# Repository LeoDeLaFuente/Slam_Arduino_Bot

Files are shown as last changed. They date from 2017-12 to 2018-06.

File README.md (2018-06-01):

Polytech

Ce projet est réalisé dans le cadre de la formation de prépa intégrée de Polytech'Nice Sophia
* * *
# Mapping with an Arduino Robot
&nbsp;&nbsp;&nbsp;&nbsp;&nbsp;&nbsp; Projet école de création d'un robot arduino permettant la cartographie d'une salle sans données GPS.

## Présentation

&nbsp;&nbsp;&nbsp;&nbsp;&nbsp;&nbsp;Slam Arduino Bot est un petit véhicule permettant de cartographier son environnement sans données GPS. 
Le robot est contrôlé par un utilisateur depuis un ordinateur. <br>

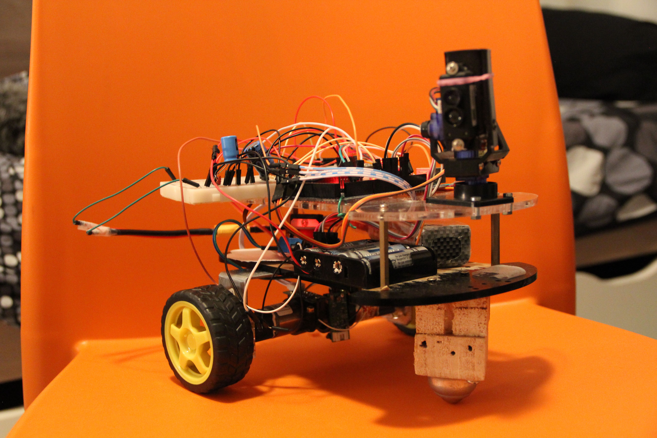
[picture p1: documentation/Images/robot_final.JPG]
Photo du robot


  &nbsp;&nbsp;&nbsp;&nbsp;&nbsp;&nbsp;Il se déplace, mesure des distances et transmet les données. Du côté de l’ordinateur, une application traite les données reçues, trace la carte 2D en fonction des données et envoie les ordres au robot.
Au début du fonctionnement, le robot s’initialise puis se connecte à l’application de l’utilisateur par wifi. Puis le robot commence à réaliser des mesures afin de scruter sont environnement. Il transmet les données à l’application qui les traites, et affiche la carte réalisée.  L’application attend les ordres de l’utilisateur concernant ses déplacements. Après avoir effectué les déplacements nécessaires, le robot va réaliser de nouvelles mesures et ainsi de suite.

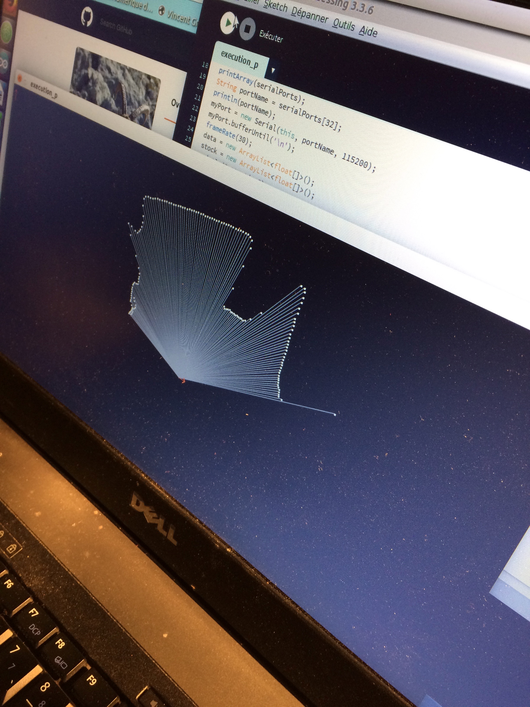
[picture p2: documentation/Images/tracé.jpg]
exemple de traitement de données


Ce projet est principalement réalisé avec une carte arduino Mega pour le robot et le logiciel processing pour l'application du coté ordinateur.

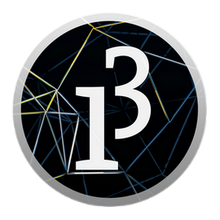
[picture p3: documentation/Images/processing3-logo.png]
Logo Processing


Après avoir travaillé à deux sur ce projet durant un semestre, nous avons finalement rendu ce <a href="/documentation/Slam Arduino Bot - compte rendu de projet.pdf">rapport</a> récapitulant notre travail.

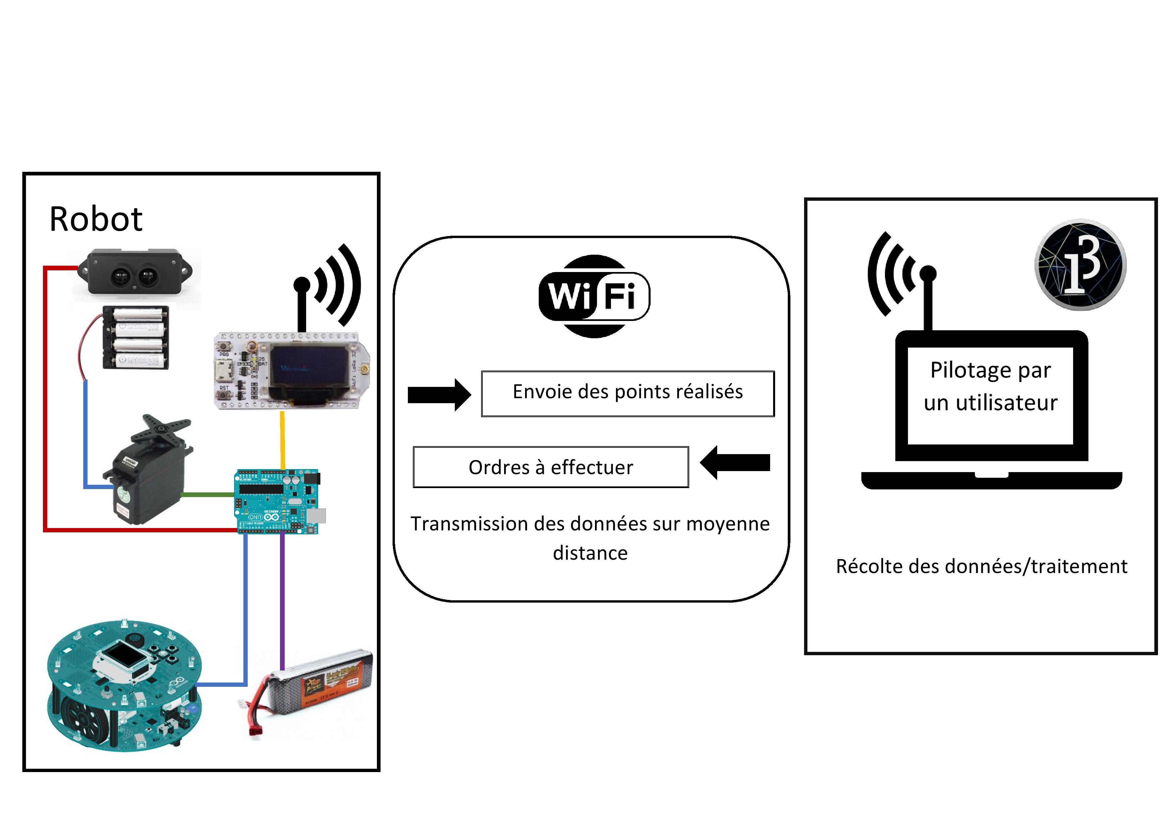
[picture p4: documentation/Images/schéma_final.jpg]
shéma projet


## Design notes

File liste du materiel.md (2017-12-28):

# Liste_du_matériel

Voici la liste du materiel que nous utilisons/utiliserons pour la réalisation de ce projet.

*****
#### ROBOT
- 2 arduinos  
  Nous utilisons 2 cartes ATMEL de type mini.
  Une carte sera embarquée sur le robot et permettra de commander les robot ainsi que de réaliser les mesures.
  Une seconde carte servira à réaliser une connexion radio fréquence avec le robot pour échanger les flux de données entre robot et ordinateur.

- carcasse  
  La carcasse du robot sera en deux etages, un premier étage où sera disposé les moteurs, la baterrie et la carte arduino. Et le second étage permetrera de fixer la tourelle de mesure.

- Antennes RF  
  Deux antennes radio fréquence permettant la communication entre les deux cartes arduinos. Antennes de type LORAM ?  

- Une batterie  
  Li

- tourelle :  
  + Un plateau pivotant  
  
  + servo moteur  
  de type ...   
  
  + laser de mesure de distance  
  de type ...  
   
  + compass ?   

- Déplacement:  
  + Deux roues codeuses  
  
  + Une roue folle

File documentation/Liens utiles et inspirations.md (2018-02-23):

# Voici une liste de tous les liens utiles

+ [transfers données arduino-ros](http://wiki.ros.org/rosserial_arduino/Tutorials/Arduino%20IDE%20Setup>)
  
+ [pdf](https://ocw.mit.edu/courses/aeronautics-and-astronautics/16-412j-cognitive-robotics-spring-2005/projects/1aslam_blas_repo.pdf)
 sur l'explication des techniques de S.L.A.M afin de traiter les données, d'en déduire son odométrie.
 
+ https://articulo.mercadolibre.com.ar/MLA-621770683-motorreductor-con-encoder-namiki-22cl-3501pg-_JM permet de savoir comment brancher nos roues codeuses
+ http://www.robot-maker.com/shop/blog/33_Asservir-moteurs-courant-continu-PID.html asservissement roue codeuse

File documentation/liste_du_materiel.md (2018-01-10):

# Liste du matériel

Voici la liste du materiel que nous utilisons/utiliserons pour la réalisation de ce projet.

*****

- 2 arduinos  
  Nous utilisons 2 cartes ATMEL de type mini.
  Une carte sera embarquée sur le robot et permettra de commander les robot ainsi que de réaliser les mesures.
  Une seconde carte servira à réaliser une connexion radio fréquence avec le robot pour échanger les flux de données entre robot et ordinateur.

- carcasse  
  La carcasse du robot sera composé de deux etages, un premier étage où sera disposé la baterrie et la carte arduino (ainsi que le systeme d'émission réception Lora) sur le dessus, et les moteurs sur le dessous. Et le second étage permetrera de fixer la tourelle de mesure.

- Antennes RF  
  Deux antennes radio fréquence permettant la communication entre les deux cartes arduinos. Ces antennes seront de type LORA permettant un échange de donné assez faible sur moyenne distance. 

- Une batterie  
  L'intensité demandé par les moteurs ne sera pas très élevé, mais nous utiliserons surement une batterie de type LiPoly que notre école à en stock, nous définirons la charge electrique et la tension nécessaire plus tard. 

- tourelle :  
  + Un plateau pivotant  
  
  + servo moteur  
  de type ...   
  
  + [laser de mesure de distance](/Construction_Projet/Laser.md)   
   
  + compas permettant une meilleure précision de rotation que les roues codeuses ???   

- Déplacement:  
  + Deux moteur/roues codeuses  
  
  + Une roue folle

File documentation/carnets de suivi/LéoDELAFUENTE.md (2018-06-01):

*******************
# Compte rendu 
*******************
## Présentation

Ce projet réalisé dans le cadre de notre cours d'arduino en PEIP2 de l'école Polytech Nice-Sophia (prépa intégré) consiste à conevoir un robot permettant de cartographier une salle. Nous allons pour cela utiliser une carte arduino.

## Seance du 21 Décembre
 - ##### Création du projet sous Github pour la remise des comptes rendus ainsi que le dépot de nos codes.
 - ##### Mise en place du projet
 - ##### Commencement de la mise en place de la liste du materiel
 - ##### Création du schéma du projet
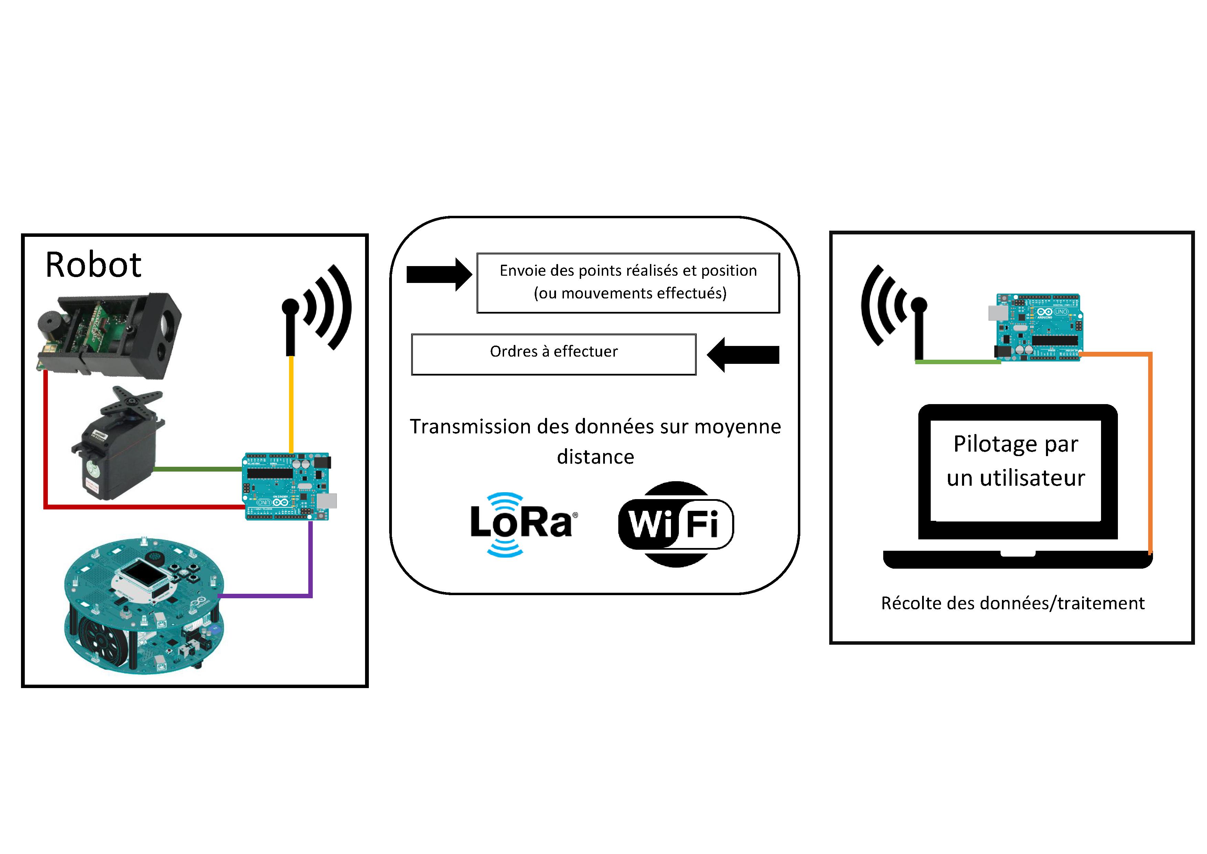
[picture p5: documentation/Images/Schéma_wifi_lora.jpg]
Schéma projet
 

 ## Travail personnel du 22 Décembre
 
  - ##### Commencement du [dessin 3d du robot](/robot) sous Autocad Inventor 
  La Base du robot sera constitué de deux planches en bois découpé à la découpe laser et reliés par quatre entretoises (en PVC ou métal). Un servomoteur sera placé sur la planche du dessus pour ensuite placer le télémetre laser dessus. Nous n'avons pas encore reçus les roues codeuses, et je n ai pas trouvé d'image 3D de celles-ci pour l'instant.
  
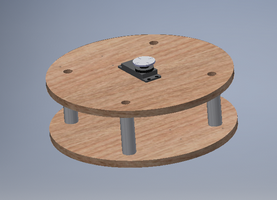
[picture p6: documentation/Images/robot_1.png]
Robot en 3D


## Seance du 10 Janvier 

 - ##### Reception du laser
 Notre professeur nous as soudé une alimentation permettant de faire fonctionné le Laser avec deux piles AA, ainsi ques les fils sur le pins Rx et Tx du laser. Félix à ainsi commencé a réaliser le code permettant de faire des mesures en boucle.
 
 - ##### Travail sur le servomoteur
  Le servomoteur que nous avons à disposition est un servomoteur étant sensé faire 180°.La rotation à 360° aurait été préférable, mais les servomteur pouvant réaliser des tours à 360° ne sont pas réellement des servomoteurs, ce sont des moteurs se comportant comme des moteurs à courant continues. Nous avons donc prévu d utiliser notre servomoteur de 180° et de demander à notre robot de faire un demi-tour sur lui meme si l 'on veux réaliser des points tout autour.  
Après avoir tester notre servomoteur 180°  nous avons constaté qu' il ne fait qu'environ 160° (amplitude exacte à définir.) Nous allons donc continuer avec celui-ci pour l instant, mais nous allons aussi surement voire pour commander un servomoteur effectuant 270° [comme celui-ci](https://fr.aliexpress.com/item/DOMAN-RC-DM-S0603D-40g-0-14s-5-5kg-cm-plastic-gear-300degree-robot-6kg-digital/32231859181.html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,searchweb201602_0_10152_10151_10613_10615_10614_10059_10314_10534_10084_100031_10083_10184_10305_10304_10307_10604_10306_10341_10065_10142_10340_10068_10343_10342_10103_10344_10302,searchweb201603_0,ppcSwitch_0&algo_pvid=1373983d-8d1d-41ea-bd80-e2dcfdbb8e0c&algo_expid=1373983d-8d1d-41ea-bd80-e2dcfdbb8e0c-20). 

## Séance du 19 Janvier

- ##### Reception des moteurs à roues codeuses
 Ayant reçu nos moteurs, je me suis penché sur leur fontionnement à l'aide d'un pont en H (L298N). Ce dernier permet de controler deux moteurs.  
 
 pont en h
 moteur à roues codeuses
  moteur à roues codeuses
 
 Nous appliquons une tension de 12V grâce à un générateur de tension pour nos tests. La mise en place du fonctionnement des moteurs à pris beaucoup de temps car j'avais utilisé un fil défaillant. Après avoir trouvé l'erreur, l'exécuion du programme permet defaire fonctionner les moteurs dans le sens voulu et de les arréter grâce aux touches du clavier. Nous avons récupéré le code présent sur [ce site](http://www.instructables.com/id/Arduino-Modules-L298N-Dual-H-Bridge-Motor-Controll/), ainsi que suivi les instructions. Ce programme m'as ainsi permit de comprendre comment fonctionne les moteurs pour pouvoir dévelloper le code qui va servir à diriger le robot.
 Il faut maintenant récupérer le signal des roues codeuses pour connaitre précisément la rotation des moteurs.  
 
 ## Séance du 22 Janvier
 
 - ##### Pésentation de notre projet devant nos deux professeur et notre classe.
 [La présentation est visible ici](https://github.com/LeoDeLaFuente/Slam_Arduino_Bot/blob/master/documentation/Slam_arduino_bot_presentation.pdf)
 
 - ##### Soudure des cables des roues codeuses.
 J ai effectué des soudure sur les fils des roues codeuse pour permettre le branchement sur notre plaque de test et relié ainsi le codage à l'arduino.
 
 ## Séance du 6 Fervier
 
 - #### Fonctionnement des roues codeuse.
  J ai fait plusieurs recherches pour trouver comment cabler la roue codeuse, et est trouvé un schéma qui n'était pas bon est qui a grillé les roues codeuse ( celle ci fontionne avec des leds, et je n'avait pas mis de résistances, sachant que le circuit de la roue codeuse n'en contient pas). J ai pu récupéré une roue codeuse avec un circuit de protection intégré qui fonctionne avec l'arduino. Il faut maintenant écrire le code permettant d'utiliser cette dernière, et acheter une seconde roue codeuse.
  
## Travail personnel du 9 Février

- #### Codage roue codeuse.
  J'ai réalisé un code ("moteur_execution") permettant defaire tourner une roue sur une longueur demandé en cm. Le programme prend donc une longueur l en cm, la convertit en "tour de roue", puis fais tourner la roue en comptant le nombre de tour graçeà la roue codeuse.

## Séance du 21 Février
- #### Fabrication du premier robot en carton.
 J'ai fabriqué le premier essai de robot en carton. Celui-ci va me permettre de faire premiers essai avec les roues codeuses et d'améliorer le fonctionnement de mon code.
 
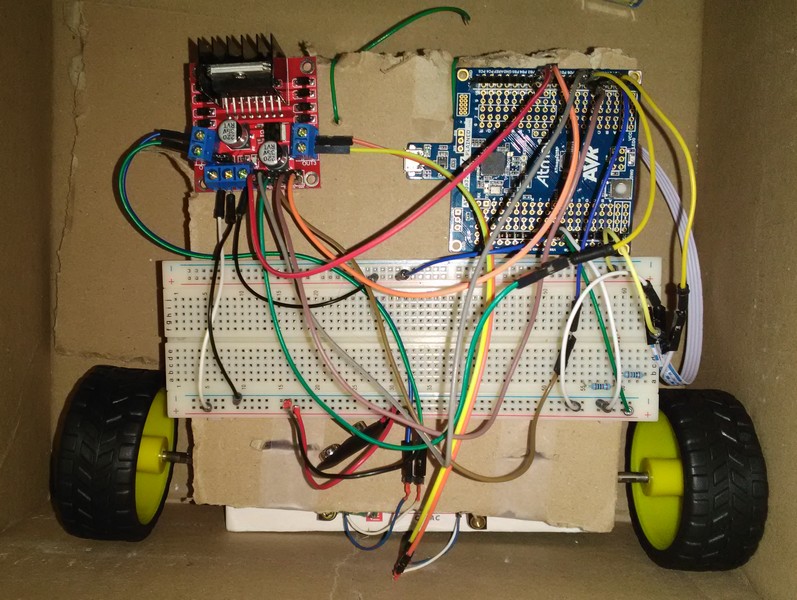
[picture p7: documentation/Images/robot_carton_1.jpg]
premier robot en carton


## Travail personnel du 22 Février
 - #### Mise en route du robot
    Après avoir récupéré une roue codeuse sur un robot d'un autre groupe qui ne s'en servait pas, j ai commencé à faire les essais pour faire tourner les roues du robot en même temps et commencer à programmer les mouvements élémentaires du robot. Je me suis aperçu que mes moteurs tournaient lentement, et pense que celà est dû au fait que j'alimente le pont en H et l'arduino avec la même pile de 9v qui n'est pas assez puissante.
    
## Séance du 12 Mars
 - #### Changement du support du robot
   J'ai récupéré un support différent permettant de faire de vrai test sur les déplacements du robot, mais il faut réadapter les moteurs pour qu'ils se fixent sur le support.
 
 ## fab lab le 20 Mars
 - #### Création d'une pièce d'adaptation
  J'ai réalisé à l'aide de la découpe laser une pièce permettant d'adaptater les moteurs à des equerres pour fixer le tout au support du robot. Il manque juste des rivets et la fixation sur le support.
  
 ## Séance du 28 Mars
 
 - #### Mouvements élémentaire
  J'ai réalisé une fonction permettant de faire avancer et reculer le robot, mais je n'ai pas pu le tester, car le robot n'est pas fini d'être monté. Je me suis par contre aperçu que les deux moteurs ne tournent pas à la même vitesse. Il va donc falloir réaliser un asservissement en vitesse sur les moteurs.
  
 ## fab lab le 3 Avril
 
 - #### Fixation des pièces avec rivets
 Après avoir acheté les rivets, je suis allé au fab lab pour fixer les moteurs aux equerres graçe aux pièces réalisé le 20 Mars. J ai aussi commencé à percer le support pour assembler les équerres au support.

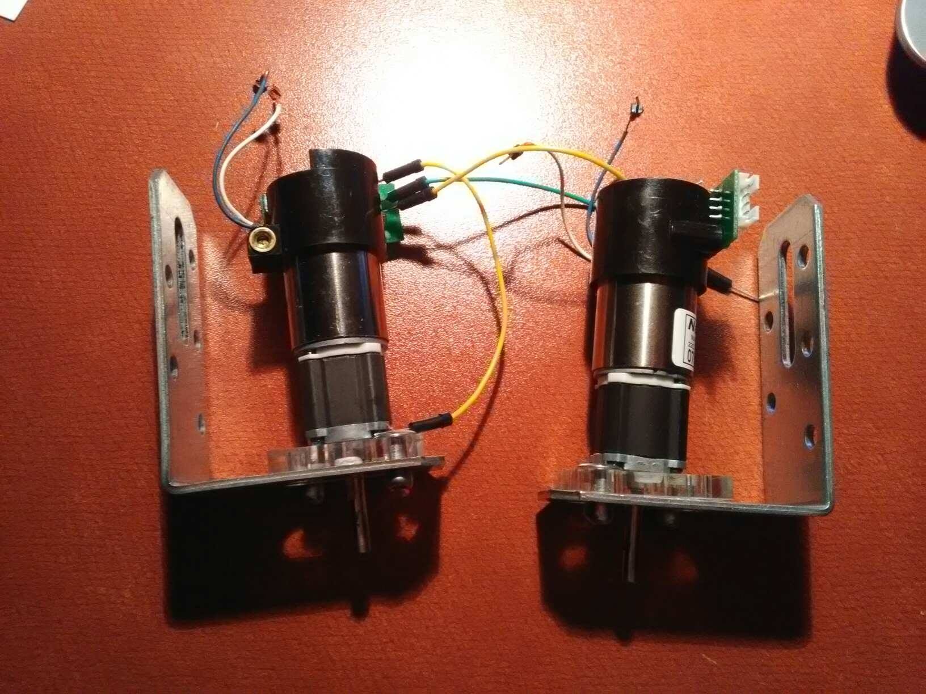
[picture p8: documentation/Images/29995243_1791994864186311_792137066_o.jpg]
assemblage equerre et moteur
  
 
 ## séance du 5 Avril
 
 - #### Présentation de mi-parcous auprès de nos professeur. 
 [Celle-ci est visible ici](https://github.com/LeoDeLaFuente/Slam_Arduino_Bot/blob/master/documentation/Slam_arduino_bot_mi-parcours.pdf). Elle nous a permit de rédéfinir notre planning et de faire le point sur notre projet.
 
 - #### Adaptations des roues.  
 Nous avons pu adapter les roues aux moteurs, nous n'avons donc finalement pas besoin d'en acheter de nouvelles.
 
 - #### Fixation des moteurs+équerres sur le support. 
 J ai rivetté les equerres sur le support, ce qui m'a permis de cabler l'ensemble moturs, pont en H, arduino et batterie sur le robot.
 <br>
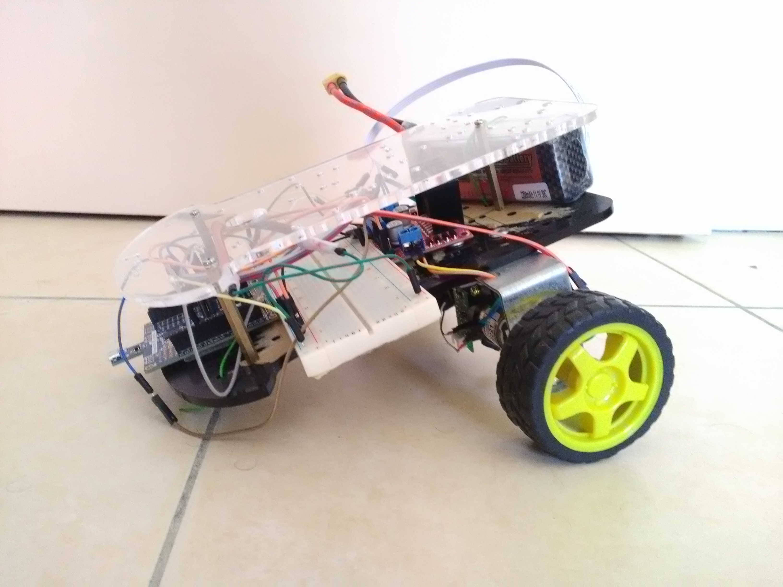
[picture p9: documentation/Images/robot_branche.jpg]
photo du robot
 
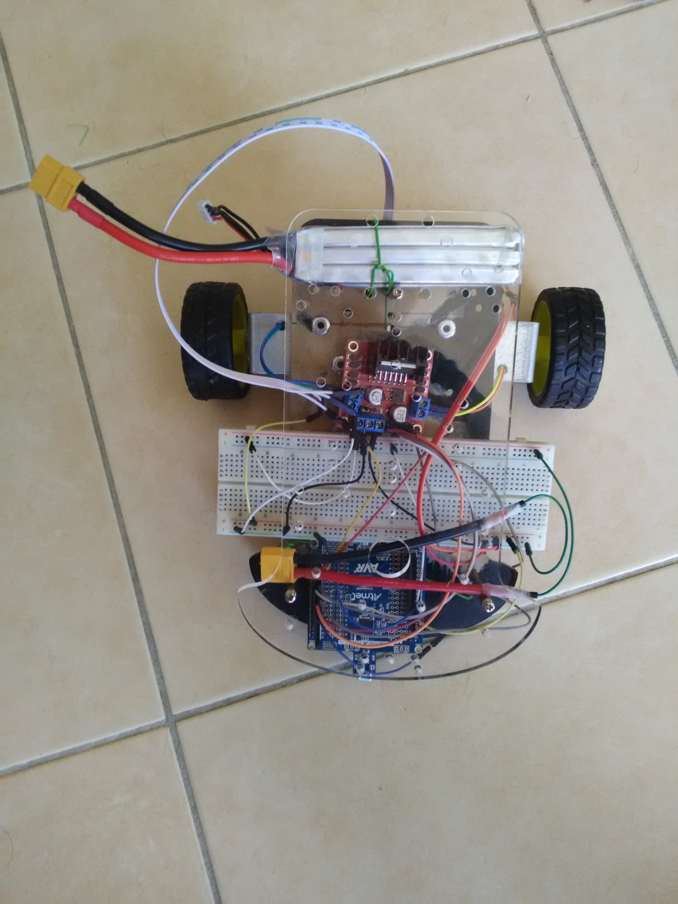
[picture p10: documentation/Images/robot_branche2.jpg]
photo du robot
 
 <br>
 [Voici la vidéo du premier branchement](https://youtu.be/iydBeL7KhAE).
 Il manque un pièce sur le devant pour surélever au dessus de la roue folle pour que le support reste bien plat, mais celui-ci n'est pas necessaire pour coder les déplacements du robot.

 ## fab lab et travail personnel du 6 Avril
 
 - #### Création de la dernière pièce manquante pour le robot
 Cette pièce en bois se situe entre le support et la roue folle pour que le dessus du robot soit de niveau.
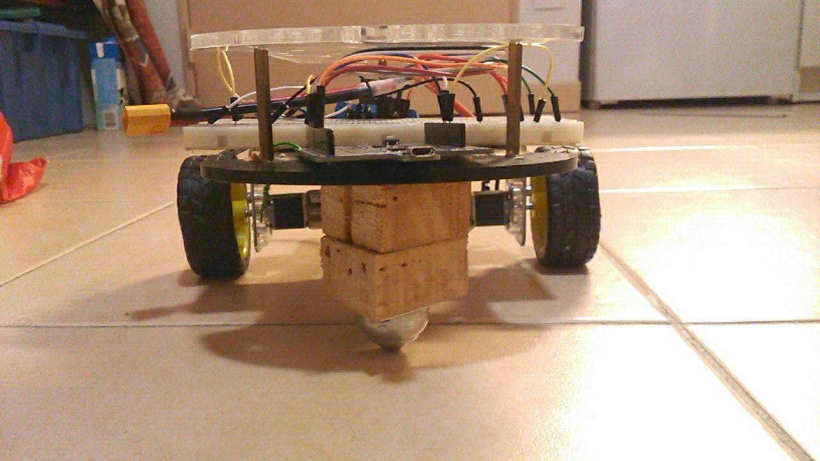
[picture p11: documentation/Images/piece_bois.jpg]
pièce en bois réalisé
 
 
 - #### Dévellopement du code sur le robot
 Le robot peut maintenant être commandé pour se déplacer en ligne droite sur une certaine distance, reculer, et tourner sur lui même dans les sens horaire et anti-horaire. [Cette vidéo montre les déplacements pouvants être effectués](https://youtu.be/h0HItliRpBA). On remarque que le robot ne se déplace pas en ligne bien droite, et que les rotations ne respectent pas bien les angles demandés (180 degrés puis 360 degrés). Cela est dû au fait que les moteurs ne tournent pas à la même vitesse. Il faut donc améliorer cela par un asservissement en vitesse des moteurs.
 
 - #### Recherche sur l'asservissement PID
  En effectuant des recherche sur l'asservissement des moteurs, j ai trouvé un code permettant de réaliser un asserviement PID, mais je n'arrive pas à adapter les constantes de proportionalité, de dérivation et d'intégration à nos moteurs.
 
 ## Travail personnel du 8 Avril 
 - #### expérimentation frottements
 Pour essayer "d'échapper" à l'asservissement en vitesse necessaire pour que les deux moteurs tournent à la même vitesse, j ai essayé de voire si le frottement des les moteurs suivait une loi linéaire, et si un coefficient e proportionnalité pouvait être trouvé entre les deux moteurs.
 Malheureusement ce paramètre ne semble pas linéaire, et je n'ai pas trouvé de coefficient de proportionnalité entre les vitesse de mes deux moteurs.
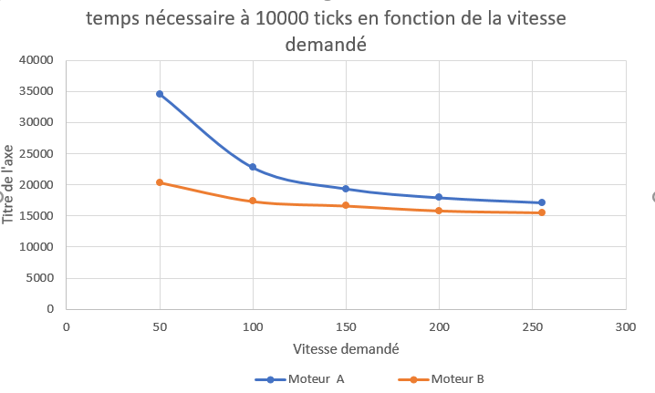
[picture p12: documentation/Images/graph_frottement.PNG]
graph du temps pour réalisé 1000ticks en fonction de la vitesse demandé des deux moteurs
   
 [Voici la feuille excel qui a produit le graph](/documentation/tableur_frottements.xlsx)  
 Le code ayant permit de faire ces calcul est un code modifié du code "robot réel" et nommé "calcul_frottements_moteurs [situé  ici](/code/autres_codes_arduino). Les mesures ont été doublé pour chaque valeur de vitesse et moteur pour avoir un résultat plus précis.

## Travail personnel du
- #### travail sur l'asservssement
## Travail personel du 27 Avril

- #### Compilation des codes asservisseent et robot_reel. Le robot ne reste stoujours pas prècis a cause du fait que le support du robot est légèrement décalé, et que les roues ne sont pas bien rondes.
Un bug est apparu sur la carte arduino : avrdude: stk500_recv(): programmer is not responding, que je ne suis pas arrive, même en réinstallant l'ide arduino. Jai donc continué à travailler avec la carte de Félix, mais après une quinzaine de téléversement, cette seconde carte à rencontré le même problème.

## Séance du 2 Avril 

- #### Résolution de l'erreur lors du téléversement.
Nous avons réinitialiser la carte, et le téléversement refonctionne (jusqu'à quand ? ). 

- #### Essai du code et amélioration des valeurs.
Les roues n'étant pas exactement parrallèles entre elles, le valeur de l'entraxe des roues tait difficilement mesurable. J ai donc procédé par tatonnement pour trouver la meilleur valeur. Le robot ne semble pas avoir d'erreur après 6 tour sur lui même dans le sens anti horaire. J ai désctivé la fonction permettant de faire des tours dans le sens horaire car celle-ci necessiterai une valeur d'entraxe un peu différente ( en exécutant 6 tour, le robot cumul une valeur d'environ 10 degrés.

## Travail personnel du 3 Avril

- #### Combinaison du lidar et du robot.
J ai regroupé les cablages du robot et du lidar sur l'arduino mega ainsi que créé un code qui est la combinaison des deux. Ainsi le robot peux maintenant se déplacer par exemple de 35 cm , faire des mesures avec le lidar, exécuter un demi-tour, puis refaire une mesure, et continuer ainsi. Il faut donc maintenant gérer les différents évènements qui vont arriver par la connexion wi-fi, pour les faire exécuter par le robot, et renvoyer les valeurs mesurées à l'ordinateur.  

[Cette vidéo montre un test du nouveau code (assemblage_1)](https://youtu.be/nSwKWuOiDY0)

## Séance du 9 Avril

- #### Travail sur les commandes du robot
J ai changé le code pour pouvoir permettre des actions simple sur le robot tout en effectuant nos mesures

## Séance du 2 Mai

- ####  Réorganisation
Pour pouvoir mieux travailler sur le projet, j ai changé les emplacements des modules : les alimentations en dans l'étage inferieur du robot, et les cablages sur le dessus. J'ai eu beaucoup d'erreurs qui se sont ajouté au robot suite à cette réorganisation. 

## Séance du 7 Mai

- #### Débogage des erreurs lié à la réorganisation
J ai du consacré une séance entière pour pouvoir comprendre d'où venaient les erreurs. 
- #### Réparation du module lidar
Notre module Lidar peut parfois commencer à bugger en renvoyant que des valeurs de distance constantes. Ces données sont donc inutilisable. J ai donc tenté de réparer  cela en ajoutant une capacité plus conséquentes entre l'alimentation et le lidar. En efet nous pensions que des appels de courants trop fort du lidar faisant que le courant de venaittrop faible pour l'alimenter. 
Cette capacité n'a pas sembler améliorer le lidar.

## Travail personnel du 25 Mai
- #### Assemblage
Nous avons travaillé ensemble avec félix pour pouvoir assembler tout le projet e final.  Nous avons un bug entre la liaison série de lrduino et l esp que nous ne comprenons pas.
- #### Rédaction
Nous avons profiter de cette séance pour commencer à rédiger le rapport

## Travail personnel du  31 Mai
- #### réorganisation, préparation de la présentation
Nous avons tenté de résoudre les bugs autour de la connexion, mais ceux-ci nous sont incompréhensible. Nous avons donc préparer notre présentation et préparer les codes pour les différentes fonctionnalités des modules.

## Séance du 1 Juin
- #### Présentation de notre projet devant la classe et nos professeurs.

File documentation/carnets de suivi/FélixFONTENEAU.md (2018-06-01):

# Cahier de suivi du projet de Félix Fonteneau

## Séance du 20 Décembre 2017

Tâches effectuées :

  + Recherches bibliographique des différentes options permettant d'aboutir à réaliser le traitement de données sur l'ordinateur (processing/ROS).

  + Décomposition des différents besoins matériels et informatiques nécessaires au projet. Schématisation de l'ensemble des modules et de leur utilités au brouillon : 
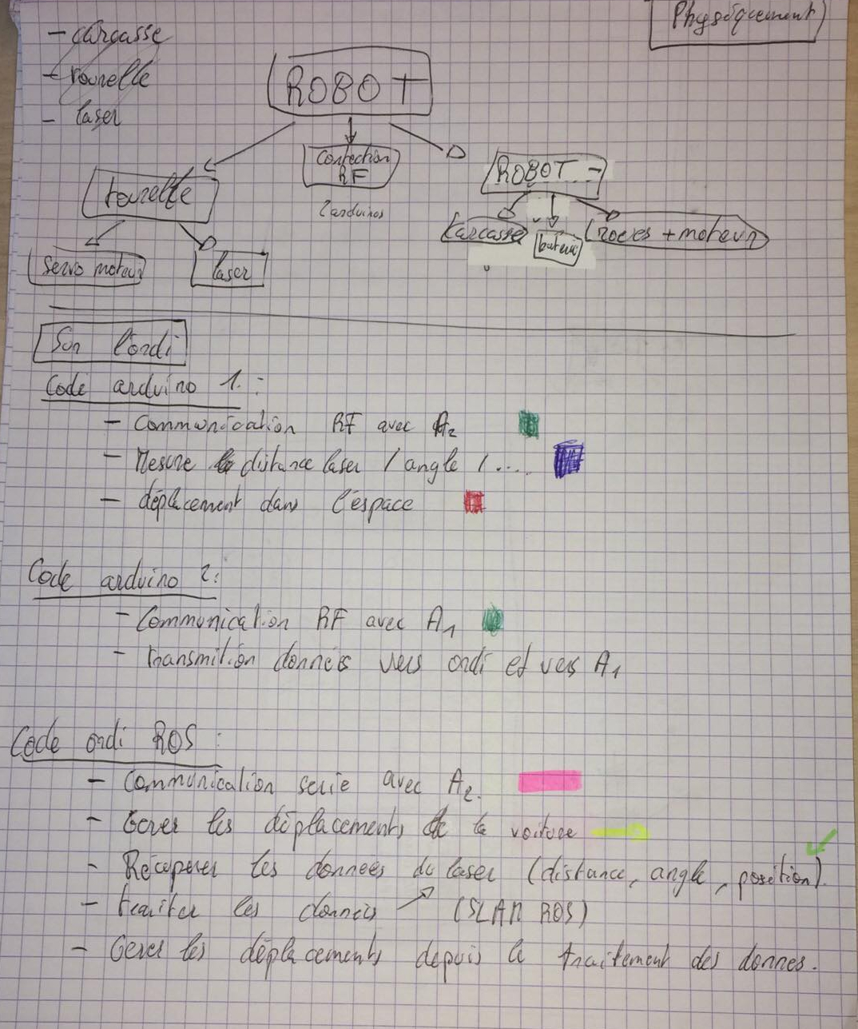
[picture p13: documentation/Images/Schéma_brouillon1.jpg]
brouillon
    
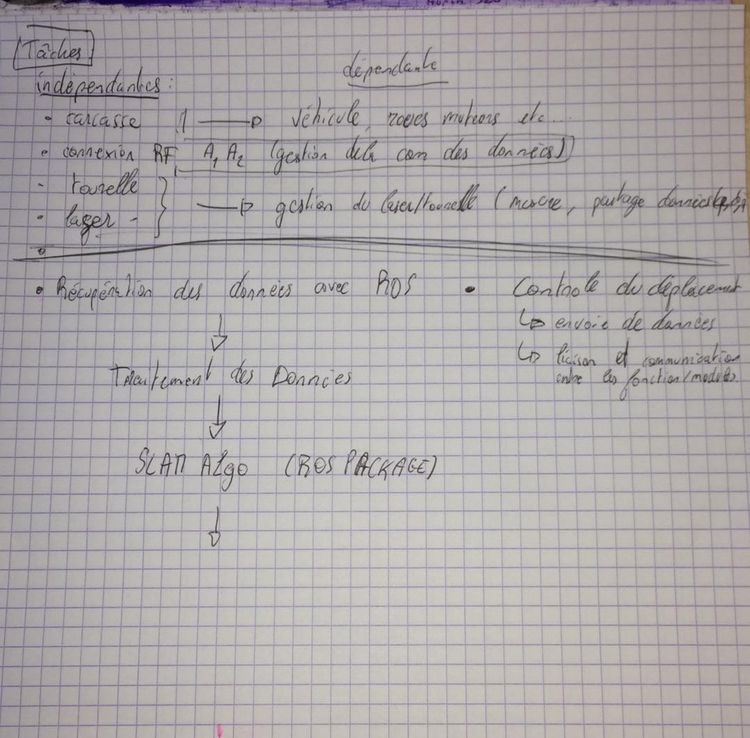
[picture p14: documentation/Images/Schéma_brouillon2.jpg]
brouillon2
  
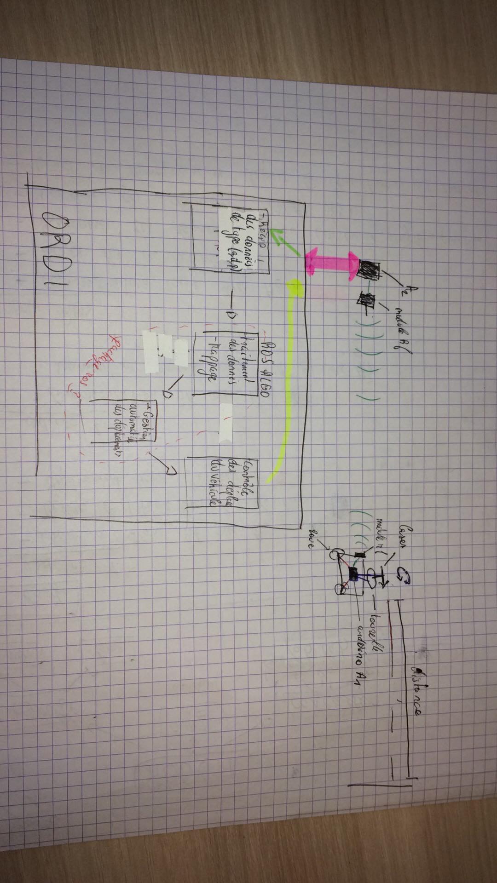
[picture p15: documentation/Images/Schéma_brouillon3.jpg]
brouillon3
  
  
  + Mise en place et déveleppement du GitHub.  
  
***  

## Travail personnel entre les séances 

Tâches effectuées :
  + Recherches et dévellopements des idées à la réalisation.  
  
  + Liste du matériel : [liste](/documentation/liste_du_materiel.md)
 
 ***  

## Séance du 8 Janvier 2018

Tâches effectuées :
  + Réception et début d'utilisation du module laser. Débuts concluants pour les premiers tests avec le laser. En effet il marche parfaitement dans les conditions dont le souhaitons. Voir : [code basique laser automatique]( /code/arduino files/test_laser_san_delay/test_laser_san_delay.ino)
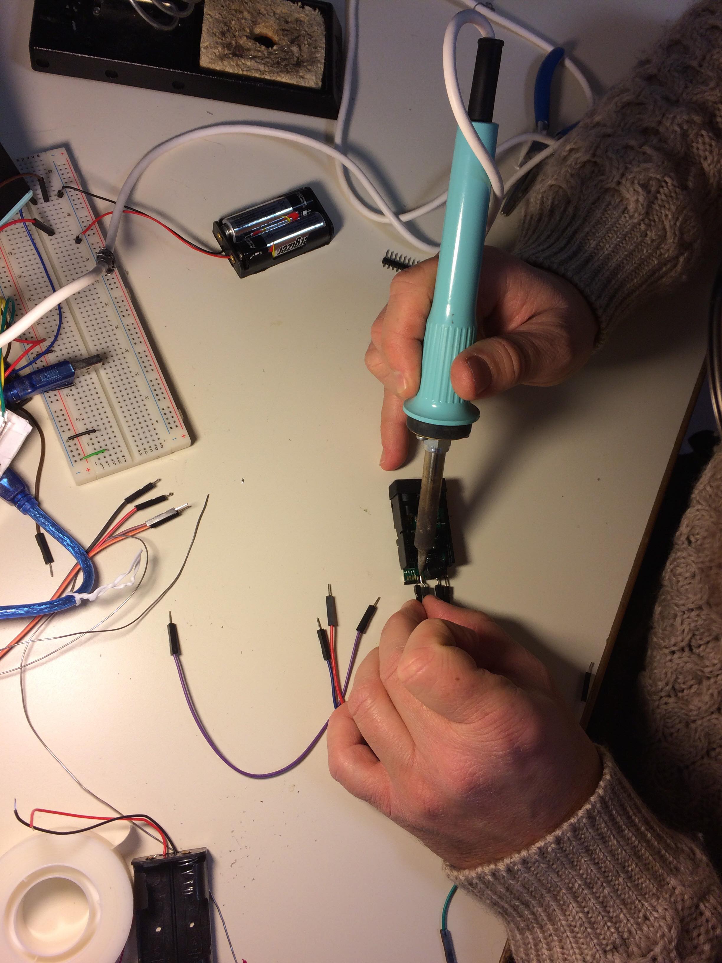
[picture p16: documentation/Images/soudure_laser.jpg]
photo soudure
  
  
  + Création de la présentation du module laser : [ici](/Construction_Projet/Laser.md)
  
  ***  
## Travail personnel entre les séances

Tâches effectuées :
  + Optimisation du code du laser
  
  + Amélioration de la vitesse des mesures
  
  ***  

## Séance du 19 Janvier 2018  

Tâches effectuées :
  + Réception des moteurs à roues codeuses (voir le carnet de léo)
  
  + Création de la première tourelle temporaire avec fil et scotch. La premiere tourelle est peu précise mais donne deja une premiere vision de la gestion des données et de comment ameliorer sa précision.
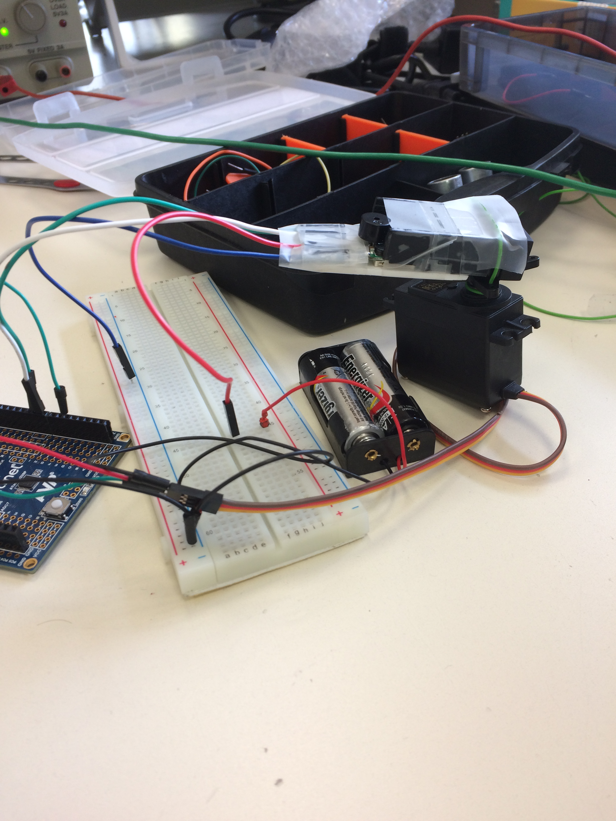
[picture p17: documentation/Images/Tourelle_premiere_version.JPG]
image tourelle
  
  
  + Harmonisation du code entre servo moteur et laser [code laser](/code/arduino_files/Tourelle/Tourelle.ino )
  
    ***  

## Séance du 22 Janvier
 
 - ##### Pésentation de notre projet devant nos deux professeur et notre classe.
 [La présentation est visible ici](https://github.com/LeoDeLaFuente/Slam_Arduino_Bot/blob/master/documentation/Slam_arduino_bot_presentation.pdf)
 
   ***  

## Travail personel durant la semaine de ski

Tâches effectuées : 
  + Création d'une simulation du laser pour débuter la programation, <a href="code/computer files/processing/execution_p/execution_p.pde"> code processing </a>
  
  + Début du traitement des données sur processing. 
  
  + Création de l'interface et de l'affichage de la carte en fonction des données reçues  
  <a href="code/computer files/processing/execution_p/execution_p.pde"> code </a>
  Cela permet de nous donner une base afin de pouvoir commencer la partie programmation en parallèle de la partie électronique.  
  
  + Le code  et l'interface sont plutôt ajustable pour convenir a des quelconques changements de projet.
  
    ***  

## Séance du 07 Février
 
 - PROBLEME   Face au trajet durant la semaine de ski, le laser a du faire un faux contact avec les piles probablement.
 
 - Tentative de ressoudage des soudures en vain.
 
 - Comparaison de l'impédance totale du laser avec l'impédence d'un laser fonctionel de même marque.  
 On remarque que les impédences sont totalement différentes (laser test de l'ordre de la dizaine d'Ohms, laser fonctionel de l'ordre du méga Ohms)
 
 - Solution : pret d'un nouveau laser pour continuer le projet.
 
   ***  

 ## Travail personel entre les séances  
 
  - Remise en état de la tourelle, mais problèmes de précision ainsi que de montage concernant cette dernière. En effet fixer stablement et précisement le laser sur la tourelle est délicat. Les cables reliant le laser au module arduino sont peu souples et tirent lors des changement d'orientation pouvant potentiellement troubler les mesures.
 
   ***  

## Séance du 21 Février

  - Changement de voie pour les mesures télémétriques du robot. 
  
  - En effet la tourelle munie d'un servo moteur permet d'effectuer environs 3 mesures par secondes avec une précision à revoir (stabilité sur la tourelle).
  
  - Mr P. Masson a commandé un Lidar pour tester cette posibilité.  
  Le lidar permetrai des mesures en "continu" et sur un axe en rotation continu. Cela augmenterai la rapidité de cartographie de notre systeme.
  
  - Les avantages :
    + Beaucoup plus de mesures effectuées.
    + Une meilleure précision grace à un nombre plus conséquent de mesures.
    + Lidar en rotation sur un axe. Cette rotation s'effectuera avec un moteur à rotation continu et une roue codeuse (pour savoir la vitesse angulaire du Lidar).
  
  - Les désavantages sont :
    + Une moins bonne précision et capacité de mesure des distances (12 m pour le Lidar, 40m pour le laser actuel). 
    + Mise en place d'une tourelle à rotation.
    + Transfert difficile pour les câbles (gestion de l'entortillement des câbles du lidar sur la tourelle).
  
  - La solution pour cette dernière difficultée est de peut être d'utiliser un slip-ring pour faire passer les cables.
  
  ***
  
## Travail personel entre les séances  
 
  - Peu de travail fut fourni sur la tourelle entre ces deux séance, j'étais en attente des pieces. Donc j'ai profité pour améliorer le code Processing. 
  
  - Arrivé du lidar peu de temps avant la scéance du 28 Mars.
  
  ***
  
## Séance du 28 Mars
  
  - Récupération d'un lidar monté sur deux servo moteur. 
  
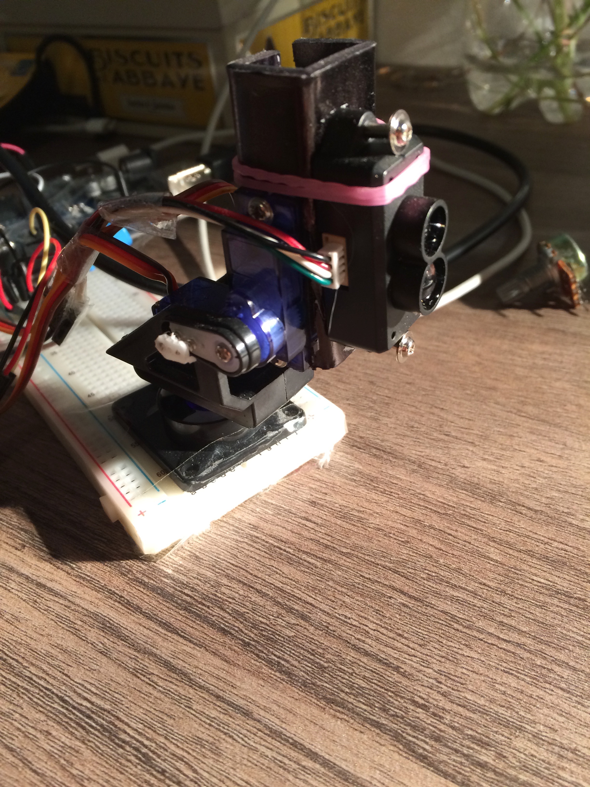
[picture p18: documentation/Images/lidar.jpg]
   
  
  - Ce Lidar n'est pas monté sur un moteur à rotation continue, il n'a donc pas besoin de slip ring pour faire passer les câbles. 
  
  - Lidar rapide (100Hz) mais la vitesse d'execution stable est plus lente environ 60Hz. 
  
  - Le lidar beug parfois et affiche une valeur en boucle pendant une centaine de mesures, problème à corriger par la suite.
  
  - Mais avant tout ce Lidar est bien mieux adapté à notre projet.
  
  - Il reste maintenant à bien adapter le fonctionnement de ce lidar au code déjà existant. Puis il faut que j'attaque les communications RF.

   ***
  
## Séance du 05 Avril 

  - Présentation de l'avancement de notre projet au reste du groupe. La voici : <a href="documentation/Slam_arduino_bot_mi-parcours.pdf" > ici </a>.
  
  - Problèmes de mesure avec le lidar. Il y a des sursaut avec le lidar de plus l'arduino mega a parfois du mal à gérer le servos moteurs aisi que les mesures.
  
 ***
  
## Travail personel entre les séances 

  - Début de construction du module RF reliant le robot à l'ordinateur. Pour cela nous allons changer un peu le le schéma de notre projet. En effet, vu le débit d'informations possibles à passer, nous allons utiliser la carte ESP 32 avec son port wifi. Le robot pourra donc immédiatement communiquer avec l'ordinateur avec une communication wifi. Le robot et l'ordinateur seront dans un premier temps connecté à un réseau commun.

  ***
  
## Séance du 10 Avril 

  - Continuité de la télécomunication wifi avec la carte esp32. 
   - Fin du module laser ! Le lidar marche enfin (presque à la perfection) et le code d'affichage est opérationnel. 
   

***
  
## Travail personel entre les séances 

  - Travail long et fastidieux sur la carte esp32.

  - L'utilisation de la carte esp 32 est difficile au début. En effet elle demande pas mal de documentation sur son paramétrage avec l'IDE arduino. De plus la connexion Wifi n'est pas très facile à gérer et demande beaucoup de temps.
  
  - Fin de la communication Wifi entre la carte esp 32 et processing. Pour cela, la carte esp 32 va se connecter à l'ip de l'ordinateur et arriver sur le server processing. Le code sur processing est très similaire à n'importe quel serveur java. Pour optimisation, on va d'abord connecter les deux éléments ensemble avec un mot de passe etc. Puis par soucis d'éfficacité, n'envoyer que les informations nécessaires par wifi.
  Cette partie m'a pris beaucoup de temps et d'investissement car elle a été difficile à cerner, puis à réaliser avec de nombreux diffonctionnements entre les connexions avec un hotspot wifi. 
  
    ***
  
## Séance du 04 Mai

  - Harmonisation du code du serveur processing, et du code de traçage de la carte en 2d.
  - Optimisation de l'application.
  
  ***
  
## Travail personel entre les séances 

  - Améliorations des échanges entre l'esp32 et l'application processing.
  
  - Création d'une simulation de nuage de points avec l'esp32 à distance.
  
   ***
  
## Séance du 14 Mai
  
  - Soudure des pins de l'esp32.
  
  ***
## Travail personel final 

  - Harmonisation finale des deux cartes (méga et esp32). Cette tâche fut de loin la plus dure et la plus compliquée. Elle fait intervenir plusieurs éléments avec beaucoup de lignes de code. Une capacité d'abstraction et de prise de recule fut nécessaire pour faire face aux problèmes rencontré. 
  
  - Au final, la connexion série entre l'esp32 et la Méga pose beaucoup de problèmes. Après de nombreusess heures à être passé à essayer de recabler ou de filtrer les données transmises. Nous n'avons pas reussi à gerer cette petite liaison qui aura causé la chute de notre projet. 


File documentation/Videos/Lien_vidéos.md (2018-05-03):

 ## Voici les liens des vidéos prises durant la réalisation du projet
 
 <hr>
 
 - #### [Premier banchement](https://youtu.be/iydBeL7KhAE)
 
 - #### [premiers déplacements élémentaires](https://youtu.be/h0HItliRpBA)
 
 - #### [Test robot + lidar](https://youtu.be/nSwKWuOiDY0)

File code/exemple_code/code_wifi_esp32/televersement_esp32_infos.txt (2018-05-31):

Afin de pouvoir televerser du code sur la carte esp32 de Heltec,
je vous redirige vers le github du constructeur expliquant tout en détail.

https://github.com/espressif/arduino-esp32

Puis regardez sur le read_me installation instructions.

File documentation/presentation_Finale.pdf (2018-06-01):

## SLAM ARDUINO BOT

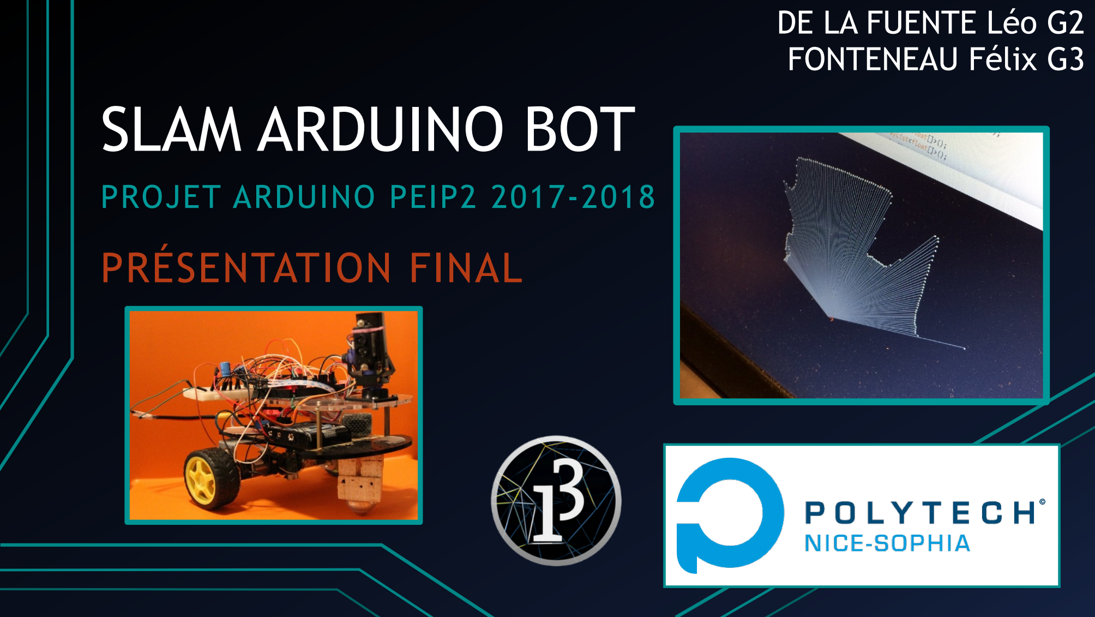
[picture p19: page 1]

PROJET ARDUINO PEIP2 2017-2018
PRÉSENTATION FINAL

DE LA FUENTE Léo G2
FONTENEAU Félix G3

## Sommaire

- Rappel du projet/changements
- Lidar
- Robot
- Connexion wifi
- Problèmes /Ce qu’il manque
- Planning et respect des tâches
- Conclusion

## Rappel du projet

Cartographie par robot en intérieur (sans données gps) avec un utilisateur dirigeant la robot à distance

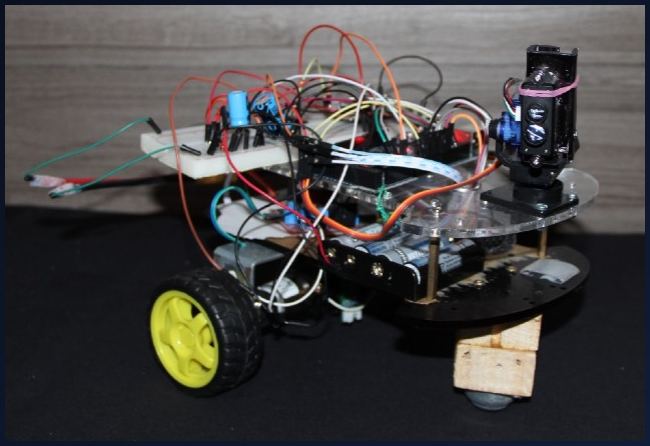
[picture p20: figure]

## Rappel du projet

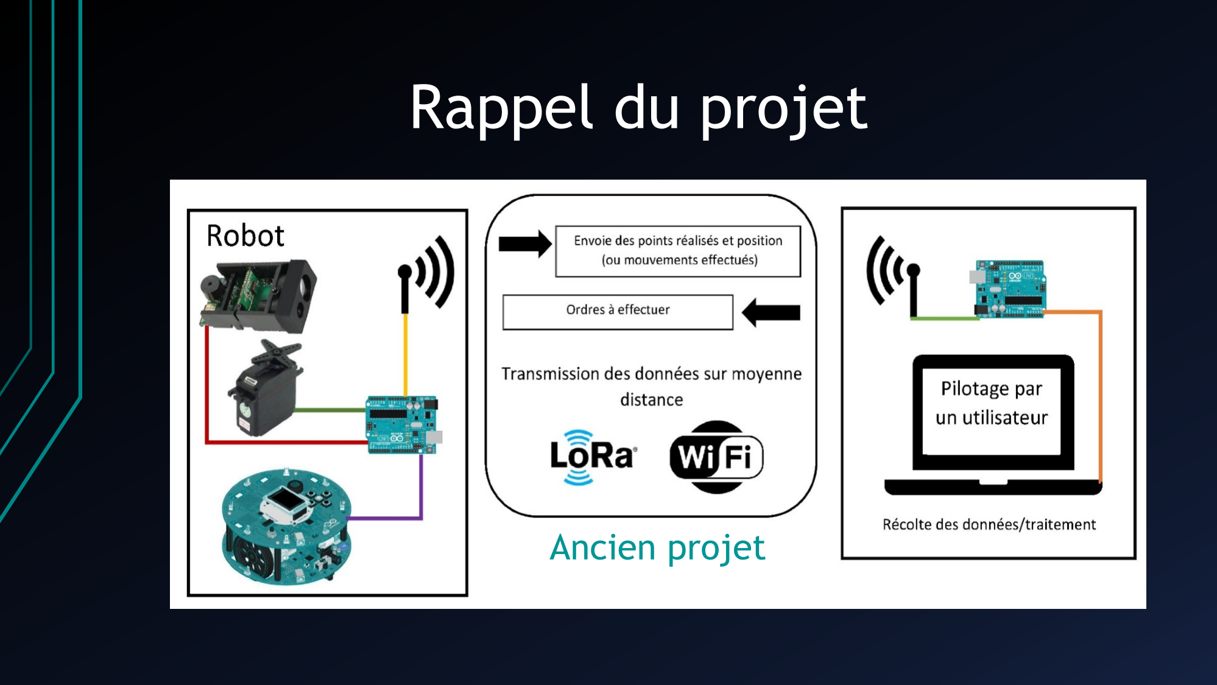
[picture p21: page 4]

Ancien projet

## Rappel du projet

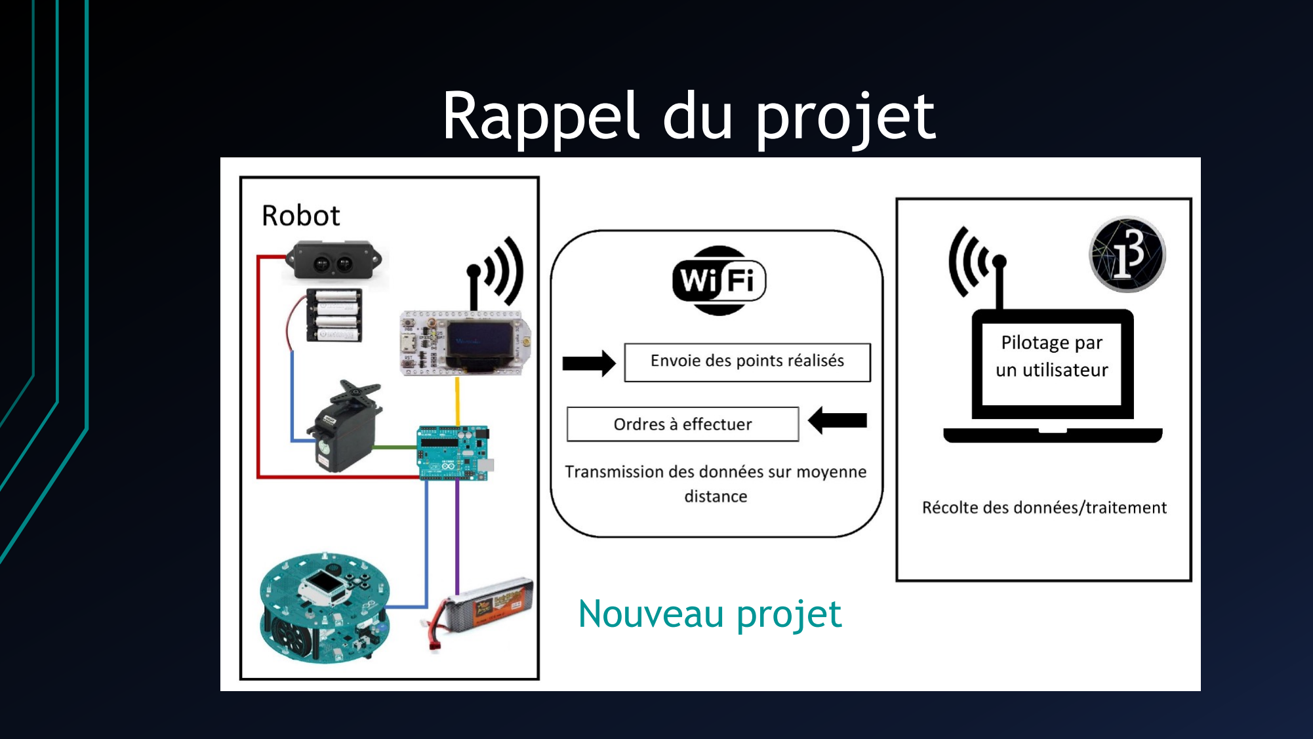
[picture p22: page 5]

Nouveau projet

### Lidar

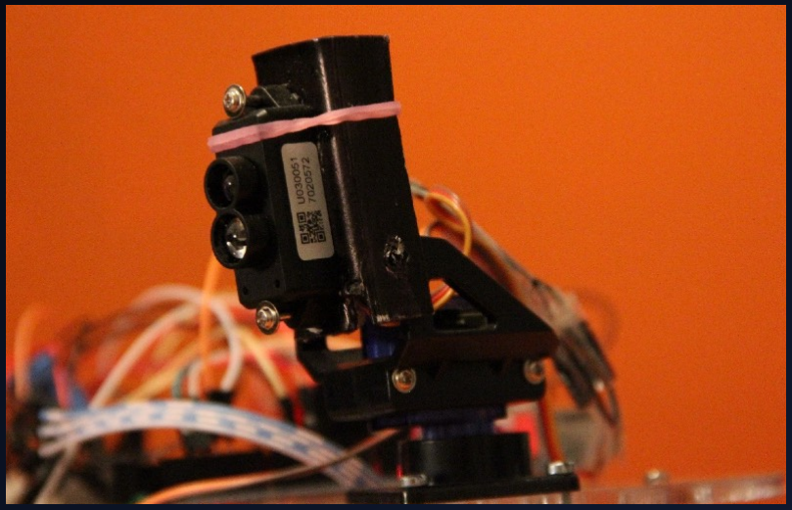
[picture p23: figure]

- Début avec un télémètre laser
- Lidar à mesure continue
- Problèmes lidar

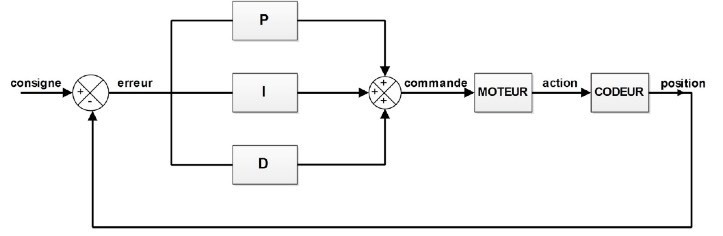
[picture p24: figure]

### Robot

- Asservissement vitesse


### Robot

- Asservissement vitesse

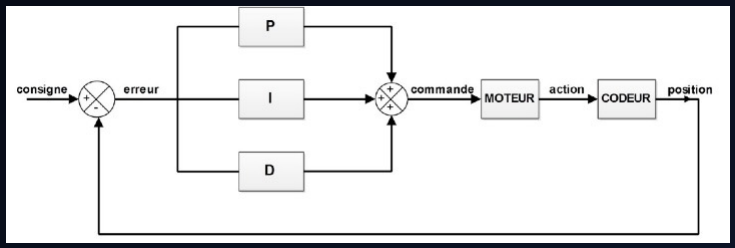
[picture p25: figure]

- Fonction élémentaires précises
- Récupère les ordres sur le port série

### Connexion wifi

- Points nombreux => connexion wifi
- Se connecte grâce à un routeur : le téléphone

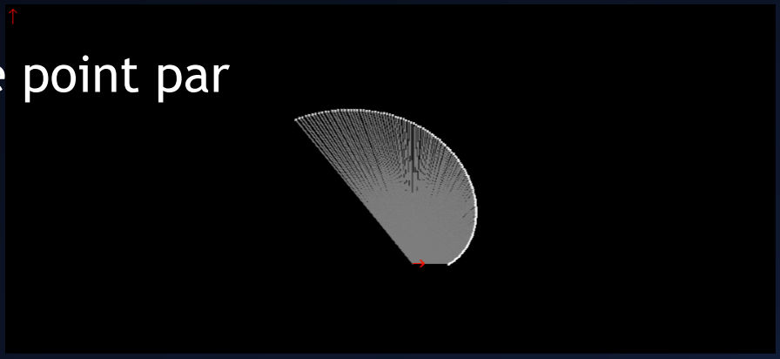
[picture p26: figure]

- Fonctionnel : génération de point par esp => affichage processing

### Problèmes/Ce qu’il manque

- Fonctionnement aléatoire du port série entre Arduino et esp32
- Codage des déplacements virtuel sur processing

Planning et respect des tâches

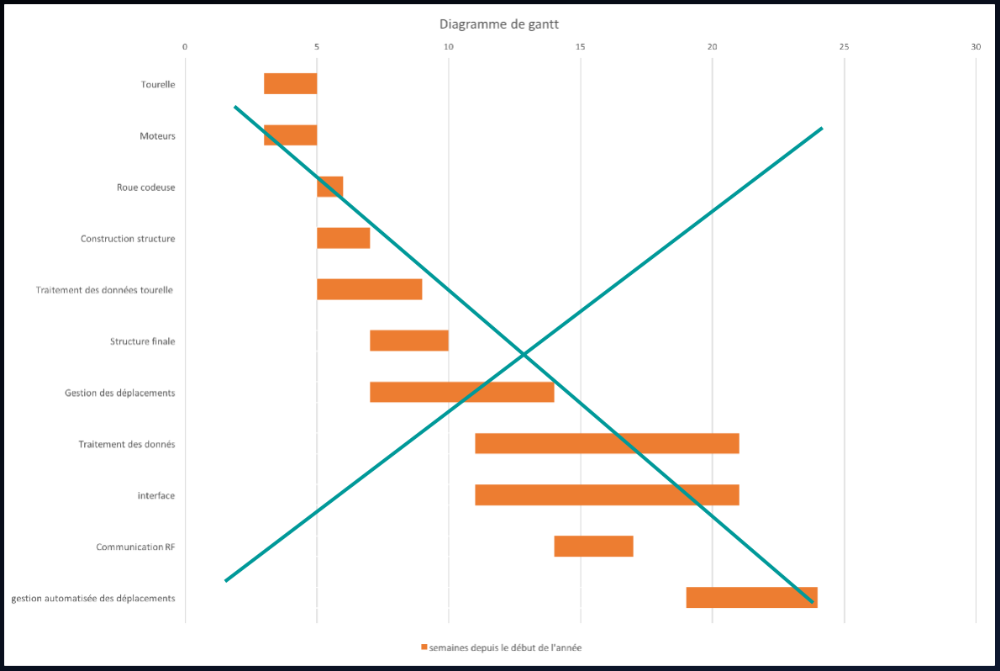
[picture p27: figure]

Planning et respect des tâches

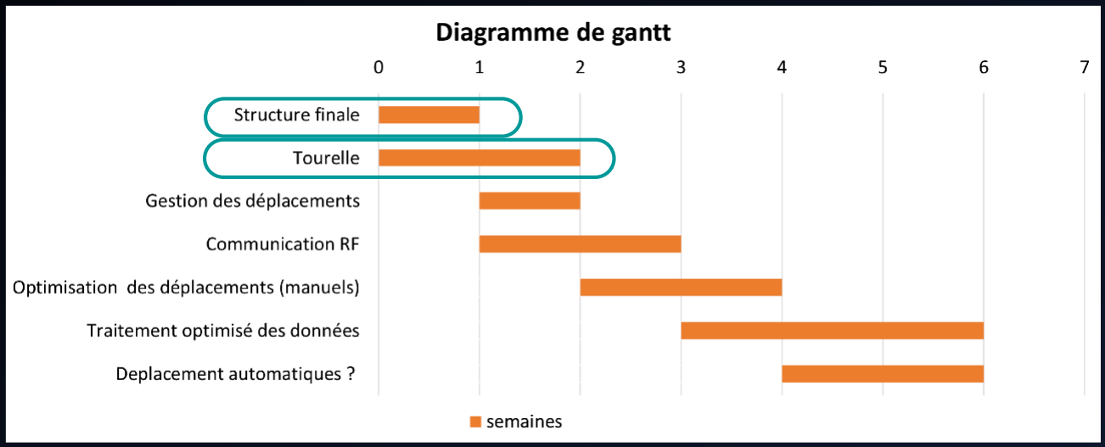
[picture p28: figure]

## Conclusion

- Communication non fonctionnel
- Assemblages différents modules pas si simple
- Expérience personnelle

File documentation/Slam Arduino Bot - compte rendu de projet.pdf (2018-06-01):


# Slam Arduino Bot

### RAPPORT DE PROJET

De La Fuente Léo, Fonteneau Félix | Electronique avec Arduino | 01/06/2018

Slam Arduino Bot

# Sommaire

1- Présentation du projet et de ses problématiques.

## 2- Robot

## 3- Lidar

## 4- Télécommunication

## 5- Informatique et traitement des données

## 6- Regroupement des différents modules

## 7- Conclusion

# 1-Présentation du projet et de ses problématiques

Slam Arduino Bot est un petit véhicule permettant de cartographier son environnement sans données GPS.

Le robot est contrôlé par son utilisateur, il se déplace, mesure des distances et transmet les données. Du côté de l’ordinateur, une application traite les données reçues, trace la carte en 2D en fonction des données et envoie les ordres au robot.

Tout d’abord, le robot s’initialise puis se connecte à l’application de l’utilisateur par wifi. Puis le robot commence à réaliser des mesures afin de scruter sont environnement. Il transmet les données à l’application qui les traites, et affiche la carte réalisée. L’application attend ensuite les ordres de l’utilisateur concernant ses déplacements qui vont être envoyé au robot. Après avoir effectué les déplacements nécessaires, le robot va réaliser de nouvelles mesures et ainsi de suite.

Nous distinguerons par la suite quatre grandes parties constituant ce projet, trois sont principalement matérielles (hardware):

- Le robot
- Le lidar
- Le module de communication

Et une partie purement informatique (software) se trouvant sur l’ordinateur de l’utilisateur.

Ces différents modules sont détaillés dans les pages suivantes.

Le problème théorique le plus important face à ce projet est l’odométrie. En effet, il est très difficile de situer exactement le robot dans son environnement. Nous y reviendrons en détail dans la partie traitement de l’information.


Schéma du projet final

# 2-Robot

### A) PRESENTATION DU MODULE

Le robot est une partie du projet qui met en relation trois domaines : la mécanique, l’électronique, et l’informatique. Sa principale utilité est de pouvoir exécuter une action de déplacement de manière précise. Cette action est récupérée depuis un port série sur une Arduino.

Les déplacements que peut faire le robot sont :

- Avancer/reculer en ligne droite d’une distance donnée
- Tourner dans le sens horaire/anti-horaire d’un angle donné

Ces fonctions élémentaires permettent de pouvoir faire se déplacer le robot en n’importe quel point de l’espace, de manière précise.

1 | Matériel :
| • Arduino :
| Le robot embarque une carte Arduino Méga permettant de recevoir les ordres et de commander les moteurs. L’avantage de ce modèle d’Arduino est de pouvoir connecter plusieurs ports séries. Ceux-ci nous seront utiles pour pouvoir commander le lidar et transmettre les informations.
| • Moteurs :
| Deux moteurs à roues codeuses permettent de réaliser les déplacements. Ces moteurs sont composés de lasers optiques qui envoient des impulsions lorsque le moteur réalise un certain nombre de tour. L’avantage de ces moteurs et de pouvoir récupérer des informations sur la rotation des moteurs par l’Arduino.
| • Pont en H L298N :
| Ce circuit permet de faire le lien entre l’Arduino, les moteurs et l’alimentation des moteurs. Le L298N permet ainsi de récupérer grâce à 3 fils les ordres de l’Arduino. Les deux premiers servent à commander le sens de rotation du moteur, en y appliquant des états haut ou bas (0 ou 5V), et le dernier permet de donner la vitesse demandé grâce à un signal PWM. Ce circuit est branché sur du 12V pour pouvoir ensuite alimenter les moteurs. Il renvoi finalement sur les deux fils du moteur le bon signal en 12V pour pouvoir faire tourner dans le sens horaire/anti-horaire le moteur, à la vitesse demandée.

- Roues :

Le robot ne possède que trois roues. Les deux premières sont positionnées sur les moteurs, et la dernière est une roue folle qui est à l’avant du robot, et qui permet de faire rouler le robot dans toutes les directions. La rotation du robot s’effectue juste avec les deux moteurs : On actionne le premier moteur dans un sens, et le second dans le sens inverse.

### B) TRAVAIL EFFECTUE

2 Premiers pas

Notre premier but était de réaliser un robot sur un bout de carton pour bien comprendre comment actionner les moteurs avec l’Arduino.

Nous avons tout d’abord mis du temps à bien câbler et comprendre le fonctionnement du pont en H, car plusieurs câbles défectueux sont venus nous rendre la tâche plus difficile. Une fois les câbles changés, nous avons pu faire les premiers tests du robot.

Nous avons ensuite changé de support en


récupérant un châssis en plexiglass. Nous avons dû pour cela réaliser dse pièces à la découpeuse laser pour adapter la fixation des moteurs. En réalisant les premiers tests sur le nouveau support nous nous sommes vite rendu compte que les moteurs ne tournent pas à la même vitesse, bien que le même ordre leur soit envoyé. Cela a pour conséquence que le robot ne se déplace pas en ligne droite.

3 Coefficient de frottement

Nous nous sommes donc demandé si l’on pouvait trouver une relation linéaire entre la vitesse demandée, et la vitesse mesuré sur chaque moteur. Cela nous aurait permis d’appliquer un facteur sur la vitesse demandé sur un des moteurs, et ainsi avoir la même vitesse finale sur les deux moteurs.
Nous avons donc réalisé un code
(calcul_frottement_moteurs)
permettant de calculer le temps nécessaire pour réaliser un certain nombre de tour du moteur. En exécutant ce code avec différentes vitesse demandées sur les deux moteurs, nous avons eu comme résultat les deux courbes ci-présentes.

Premier support du robot en carton


Les courbes nous ont montré que le frottement n’était pas du tout linéaire. Une solution simple et efficace n’était donc pas envisageable en appliquant un coefficient de proportionnalité.

4 Asservissement

Un asservissement en vitesse s’est donc imposé comme la solution à notre problème.

« Mais qu’est-ce qu’un asservissement en vitesse ??? »

L’asservissement en vitesse d’un
moteur est une méthode permettant de réguler précisément la vitesse de rotation du moteur en fonctionnant en boucle. Cette boucle commence par envoyer un ordre au
moteur, puis calcul la vitesse de rotation
du moteur grâce à la roue codeuse, et


réajuste l’ordre donné pour que la vitesse du moteur soit au plus proche de la valeur attendue. Cet algorithme est exécuté indéfiniment pour réajuster en temps réel la valeur de la vitesse.

La réalisation de cet asservissement qui s’exécute toutes les 10 milliseconde permet ainsi que les deux moteurs tournent à la même vitesse.

Notre robot peut grâce à cela se déplacer en ligne droite, et tourner sur lui-même.

5 Calcul de distance

Une variable de comptage est incrémentée à chaque impulsion lu sur les roues codeuses. Celle-ci nous permet de réaliser l’asservissement en vitesse, mais nous permet aussi de connaitre la distance effectuée par le robot. Le rapport de réduction étant de 1:80 et sachant que l’on récupère deux impulsion par tour, on sait que lorsque l’on reçoit une impulsion, la roue a parcouru 1/160ième de son périmètre. On peut donc en connaissant le périmètre de nos roues, déduire le nombre d’impulsion nécessaire pour que le robot parcourt une distance donnée. Comme les moteurs ne peuvent pas être arrêter et comportent une roue libre, nous avons fait attention à faire ralentir le robot lorsqu’il commence à se rapprocher de son point d’arrivé.

Pour ce qui est de la rotation, le calcul est réalisé en connaissant l’entraxe de nos roues. Les roues possédant un léger décalage d’alignement, nous avons été contraints d’appliquer une correction sur la valeur mesurée sur l’entraxe des roues. Celle-ci ne s’appliquant que pour la rotation dans le sens horaire, le robot ne peut finalement exécuter que des tours dans ce sens pour avoir une mesure précise de la rotation effectuée.

Source : naytech.blogspot.com

### C) PROBLEMES RENCONTRES

Nous avons grillé nos premières roues codeuses en appliquant une tension trop forte dessus car la data sheet des roues codeuses était dans un premier temp introuvable, et nous les avons donc branchés selon la data sheet d’une roue codeuse semblable. Nous avons été obligés d’en récupérer deux nouvelles.

### D) BILAN

Finalement le robot se déplace bien tout droit d’une distance donnée et réalise bien l’angle demandé en tournant sur lui-même. Cette rotation ne se fait que dans le sens horaire mais cela n’est pas très pénalisant. Le robot est autonome grâce à la batterie lipo 12V qu’il embarque qui alimente les moteurs, l’Arduino et le pont en H.

# 3-Le Lidar

### A) PRESENTATION DU MODULE

Le module lidar est l’élément permettant de réaliser les mesures de distance via envoie d’ondes électromagnétiques.

Il s’alimente en 5V et est monté sur deux servomoteurs. Ces deux servomoteurs permettent d’effectuer des rotations sur un axe vertical et horizontal afin de pouvoir faire un nuage de points. Chaque point est associé à une norme et un angle selon les servomoteurs.

Le lidar va effectuer des mesures avec une fréquence maximale de 10 Hz dans notre cas. Même si les mesures peuvent être plus rapides (max 100Hz), la précision sera très réduite.

### B) TRAVAIL EFFECTUE

Pour la construction de ce module, nous avons tout d’abord utilisé un télémètre laser monté sur un seul servomoteur. Ce télémètre était très précis et pouvait effectuer des mesures allant jusqu’à 40m. Le problème est que la fréquence des mesures était très faible : environ une mesure toute les 0,3 secondes. De plus il ne fallait pas que le module bouge lors de l’acquisition.

Télémètre laser de marque HIREED

Après un court-circuit de ce laser qui le rendu non opérationnel, nous nous sommes tournés vers un lidar. Celui-ci a la particularité d’effectuer des mesures en continu sans attendre d’ordre quelconque et à une fréquence élevée (voir présentation du module).

Nous avons aussi fait un code sur Processing afin de traiter les données recueillies.

Utilisé au début du projet


Nouveau lidar

### C) PROBLEMES RENCONTRES

Premièrement, nous avons eu un problème de court-circuit avec le laser comme précédemment cité.

Puis un problème récurrent et non résolu concernant le lidar définitif. En effet, le lidar TF-mini que nous utilisons, est de basse qualité. Quand il mesure en continu, il va , par moment s’interrompre et afficher des valeurs constantes aberrantes. L’arrêt de ces mesures ne peut être rétabli, car le module ne reçoit aucune information.

Nous avons pensé au début que son alimentation n’était pas suffisante, c’est-à-dire que l’élément demandé trop de courant par saccade. Nous avons donc changé son alimentation et mis en parallèle une grosse capacité permettant de pallier le manque d’intensité, mais cela n’a pas résolu le problème.
Une tentative de le débrancher et rebrancher automatiquement fut envisagée, mais inefficace. Nous avons donc un module lidar, affichant de temps en temps des mesures erronées, sans que nous sachions pourquoi.

### D) BILAN

Le lidar est un module qui remplit à moitié sa tâche, il fonctionne très bien en temps normal, mais il arrive indépendamment de l’état du robot, que le laser plante et affiche des données erronées.

Il a cependant permis de faire progresser grandement le projet, et au long terme, le remplacer par un lidar plus fiable est nécessaire.

# 4-Télécommunication

### A) PRESENTATION DU MODULE


Le module de télécommunication permet de transmettre les mesures effectuées par le robot à l’utilisateur, mais aussi les ordres de l’utilisateur au robot.
Pour cela nous utilisons la carte esp32 wifi-kit de Heltec pour sa souplesse entre Lora et wifi.

Afin de connecter l’application à l’ordinateur (processing) et l’esp, il faut que les deux éléments se trouvent sur le même réseau. Nous avons donc utilisé un
réseau wifi fermé tel qu’une box ou un téléphone en
partage de connexion.

L’application (processing) agit comme serveur, elle va attendre la connexion de l’esp32 avant d’établir la communication. L’esp joue donc le rôle de client. Dès que la première connexion est établie, les deux éléments communiquent par question/réponse afin de transmettre les données.

### B) TRAVAIL EFFECTUE

Tout d’abord, avant de programmer sur la carte, il faut mettre à jour l’IDE Arduino afin de pouvoir téléverser sur l’esp. Cette mise à jour ne marche pas tout le temps et est plutôt laborieuse.

La communication par wifi entre la carte et l’ordinateur demande des connaissances et notions de base avant de pouvoir l’utiliser. De plus toutes les méthodes et protocoles ne sont pas forcément évidents, ils demandent un certain investissement et temps de manipulation avant d’être compris.

Cependant Heltec nous offre de nombreux exemples de code réalisant différentes connexion ou fonctionnalités, cela permet d’y voir plus claire.

### C) BILAN

Cet élément a été plutôt chronophage et difficile à appréhender et nous a demandé beaucoup d’investissement. Mais après beaucoup de temps passé, le module marche très bien. La connexion entre l’esp et l’ordinateur est bonne et fiable.

Esp32 wifi-kit

# 5-Informatique et Traitement des Données

### A) PRESENTATION DU MODULE

La partie d’implémentation d’une application sur l’ordinateur a été un point essentiel dans le développement de notre projet.


Elle se compose en trois sous-parties.

− La première est la programmation d’un serveur sous processing afin de pouvoir récupérer les données.

− La seconde est la réception, traitement et stockage des données dans une base de données.

− La dernière concerne l’interface graphique traçant la carte et les interactions avec l’utilisateur.

### B) TRAVAIL EFFECTUE

Tout d’abord, la première chose réalisée fut le traitement des données en parallèle de la construction du module laser.

Cette manipulation ne fut pas si facile. En effet à chaque vecteur (distance ; angle) il faut associer un trait et un point sur la carte en fonction de paramètres trigonométriques afin de se ramener au centre de rotation.

Tracé de carte avec les données du lidar


Après avoir traité les données, la réalisation de la carte se fait grâce à l’interface de base de processing. Des fonctionnalités supplémentaires telles que le zoom ou le fait de se déplacer dans la carte ont été ajouté.

Puis en parallèle de la partie Télécommunication, nous avons développé le serveur wifi sous processing afin de récupérer les données de l’esp32. Le fonctionnement du serveur se base sous la forme suivante : acceptation de la communication => réception des données => réponse du serveur (ordre à envoyer).

### C) BILAN

Le bilan de ce module est plutôt positif, l’application sert de passerelle entre l’utilisateur et le robot, afin de mieux cartographier son environnement.

# 6-Regroupement des différents modules

Les différents modules étant réalisés et fonctionnant de manière indépendante, il a fallu les combiner pour réaliser le projet final.

### A) COMBINAISON LIDAR ET ROBOT

Dans un premier temps nous avons assemblé les codes du lidar et du robot pour que le robot puisse réaliser les mesures au bon moment. Cela a pu se faire en réalisant une nouvelle fonction dédiée spécialement à la prise de mesure du laser, et en faisant attention à réinitialiser les mesures d’asservissement à la fin de ces données. En effet, le programme d’asservissement qui s’exécute toutes les 10 millisecondes et faussé après un temps durant lequel le robot reste statique. On met donc à zéro tous les compteurs avant d’exécuter une nouvelle action.

### B) COMBINAISON ESP32 ET ARDUINO

La connexion entre l’Arduino et l’esp se fait par un port série. L’esp ne recevant que des informations en 3.3V, nous avons réalisé un pont diviseur de tension entre la transmission de l’Arduino est la réception de l’esp.

C’est à ce moment-là que les problèmes sont apparus…

La connexion en port série entre l’Arduino et l’esp est devenu assez aléatoire. Parfois les valeurs que l’on voulait échanger se transmettaient bien, avec de temps en temps de mauvais caractère qui apparaissaient. D’autre fois nous ne recevions plus rien sur aucune des cartes alors qu’aucun branchement n’a été changé et que les codes restaient strictement identiques. Et enfin nous avions de temps en temps des caractères incompréhensibles qui étaient échangés entre les cartes alors que nous ne souhaitions pas envoyer de données.

Nous avons pu ainsi avoir quelques données échangées entre le robot et processing, mais sur la centaine de points envoyé par l’Arduino, une dizaine seulement étaient affichés sur l’écran de processing.

Nous n’avons malheureusement pas pu résoudre ce problème qui nous rend impossible le fait de terminer le projet entièrement.

### C) BILAN DU REGROUPEMENT DES MODULES

La tache consistant à regrouper les modules nous paraissait plutôt aisé, et à finalement était l’un des plus gros problèmes. Celui-ci qui nous à pris beaucoup de temps et à finis par bloquer la réalisation final du projet.

# 7-Conclusion

Le projet consistait à réaliser un robot dirigé par un utilisateur pour scanner une pièce et en faire une carte 2D sur un ordinateur. Nous l’avions découpé en 3 modules différents que nous sommes arrivés à faire fonctionner indépendamment. Le regroupement entre le robot et l’esp permettant la connexion wifi n’as finalement pas pu être réalisé à cause de nombreux problèmes que nous avons rencontré et que nous ne sommes arrivé à résoudre. Le projet ne réalise donc finalement pas la tâche demandée, mais il n’en est pas très loin.

Cet expérience nous a permis de comprendre les difficultés que l’on peut avoir lors de la réalisation d’un projet, et qu’il est difficile de prévoir la durée des tâches à effectuer pour avoir un planning juste. Il nous a aussi permis de nous rapprocher encore plus de l’environnement Arduino, tout en nous demandant des connaissances dans des matières et des domaines que l’on ne connaissait pas (processing, mécanique). Cela nous a aussi permis d’apprendre à rechercher par nous-même des solutions aux problèmes que l’on peut rencontrer.

La taille conséquente du projet nous demandé de faire attention à bien avancer pas à pas et à ne pas négliger certaines parties. De plus des capacités d’abstraction et de prises de recules ont été nécessaire afin de bien organisé les différents interactions entre toutes les partie du projet.

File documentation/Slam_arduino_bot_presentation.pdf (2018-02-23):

# SLAM ARDUINO BOT


PROJET ARDUINO PEIP2 2017-2018

DE LA FUENTE Léo G2
FONTENEAU Félix G3

# Sommaire

- Présentation projet
- Schéma et fonctions
- Matériel
- Planning et répartition des sous parties
- Conclusion / Perspective

# Présentation du projet

QU’EST CE QUE LE SLAM ?

- Simultaneous localization and mapping


- Une technologie complexe en essor avec une forte demande


- Odométrie

# Présentation du projet

NOTRE PROJET

- Cartographie par robot en intérieur (sans données gps)


- Système de nuage de point
- Utilisateur dirigeant la robot à distance
- Création d’une carte sous processing

# Schéma et fonctions


Pilotage du
robot par un
utilisateur

- 2 Roues
- Roue folle
- Pont en H(L298N)

# Matériel

ROBOT

- Arduino
- Carcasse
- 2 Moteurs à roue codeuse
- Batterie
- Antenne RF ESP32 LoRa SX1278 (wifi/lora)
- Tourelle
- Laser
- Servomoteur

ORDINATEUR

- Arduino
- Antenne RF ESP32 LoRa SX1278 (wifi/lora)

# Planning et répartition du travail


# Planning et répartition du travail

FÉLIX

- Tourelle laser
- Traitement des données
- Liaison RF

LÉO

- Gestion des moteurs
- Construction carcasse robot
- Déplacement du robot

# Conclusion

Robot de cartographie Indoor géré à


distance par un utilisateur.

# Perspectives

- Automatisation des déplacements


- Passage sous ROS

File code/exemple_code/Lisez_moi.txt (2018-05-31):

Dans ce dossier, vous allez trouver différents exemples de codes qui nous ont aider
dans ce projet.

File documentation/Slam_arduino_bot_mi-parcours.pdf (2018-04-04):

# SLAM ARDUINO BOT


PROJET ARDUINO PEIP2 2017-2018

### PRÉSENTATION DE MI-PARCOURS

DE LA FUENTE Léo G2
FONTENEAU Félix G3


# Sommaire

- Rappel du projet
- Avancement/problèmes
- Récap matériel
- Reprise des objectifs
- Restructuration du planning
- Conclusion


# Rappel du projet

Cartographie par robot en intérieur (sans données gps)

avec un utilisateur dirigeant la robot à distance


## Avancement/problèmes


## - Tourelle de mesure


## Avancement/problèmes

## - Lidar


- Fréquence de
mesure élevée
- Précision
moindre mais
peu gênant

## Avancement/problèmes

## - Interface/traitement des données


## Avancement/problèmes

- Robot : ce qui fonctionne
- Branchement moteurs et acquisition roues codeuses


- Adaptation des moteurs


## Avancement/problèmes


- Robot : problèmes rencontrés
- Roue codeuse
- Vitesse moteur => asservissement

## Avancement/problèmes

- Robot : ce qu’il reste à faire
- Finir la construction du support
- Finir de coder les déplacements élémentaires
- Commander et placer de nouvelles roues
- Liaison robot/ordinateur

## Matériel manquant/non utilisé

### - Cartes lora/wifi


### - Roue/adaptateur pour moteur définitif

## Objectifs


## Ancien planning


## Nouveau planning


# Conclusion

- Problèmes prennent vite du temps sur le planning
- Planning non respecté mais réadapté
- Reste une bonne partie de réglages
- Communication RF à commencer

## Ouverture


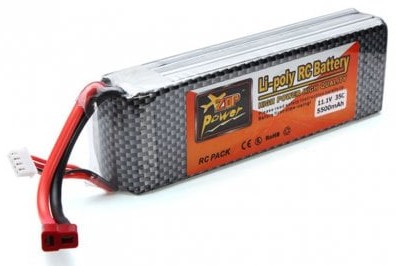
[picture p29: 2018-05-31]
documentation/Images/lipo.jpg

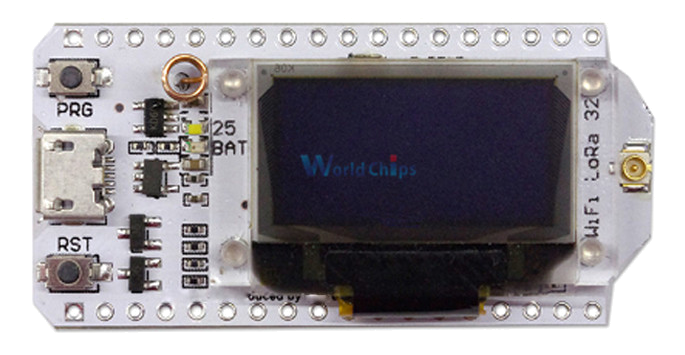
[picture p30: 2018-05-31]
documentation/Images/esp.png

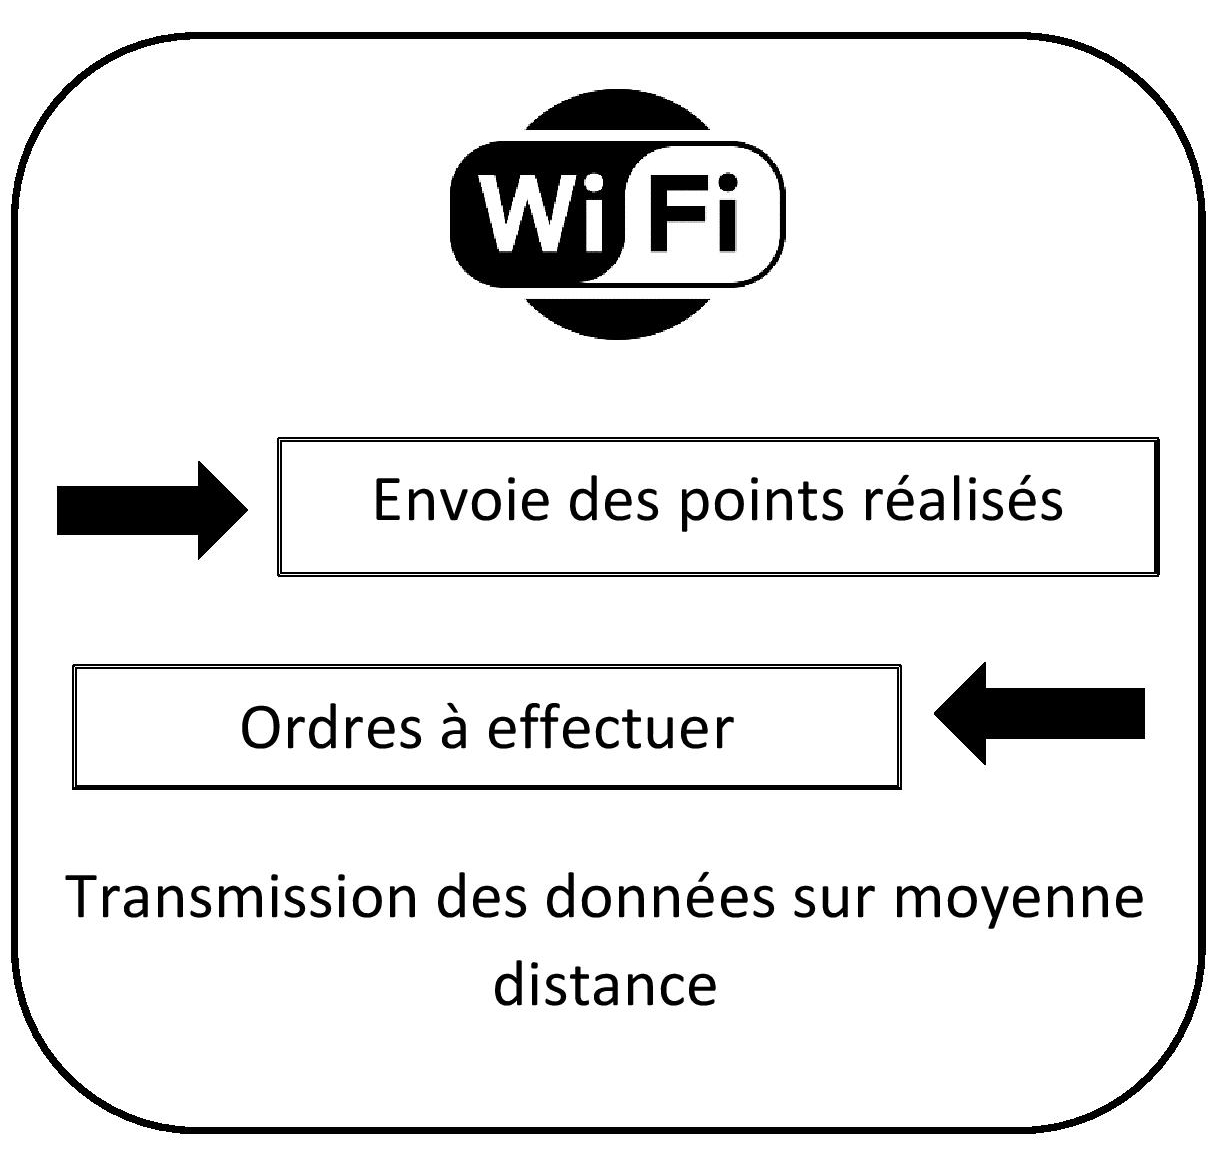
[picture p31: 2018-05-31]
documentation/Images/schéma_wifi.jpg

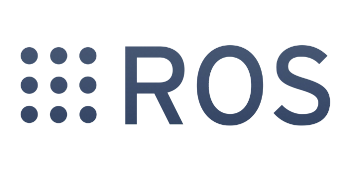
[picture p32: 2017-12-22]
documentation/Images/rosLarge.png

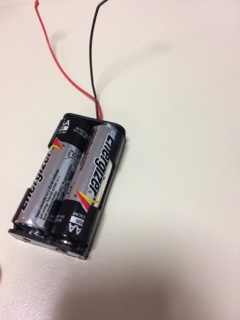
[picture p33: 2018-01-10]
documentation/Images/pile.jpg

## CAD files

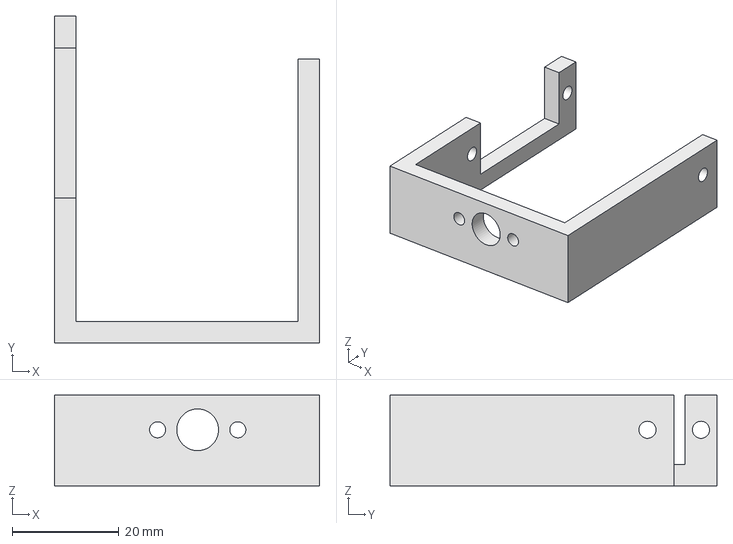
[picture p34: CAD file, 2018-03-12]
documentation/Lidar-Mount-3D-Print/LIDAR-Servo-Housing.fcstd
49.6 x 61.1 x 17.0 mm

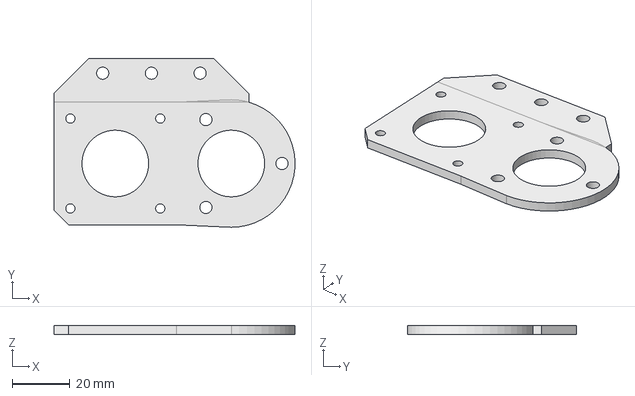
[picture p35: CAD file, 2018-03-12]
documentation/Lidar-Mount-3D-Print/LIDAR-Sensor.fcstd
83.1 x 58.1 x 3.00 mm

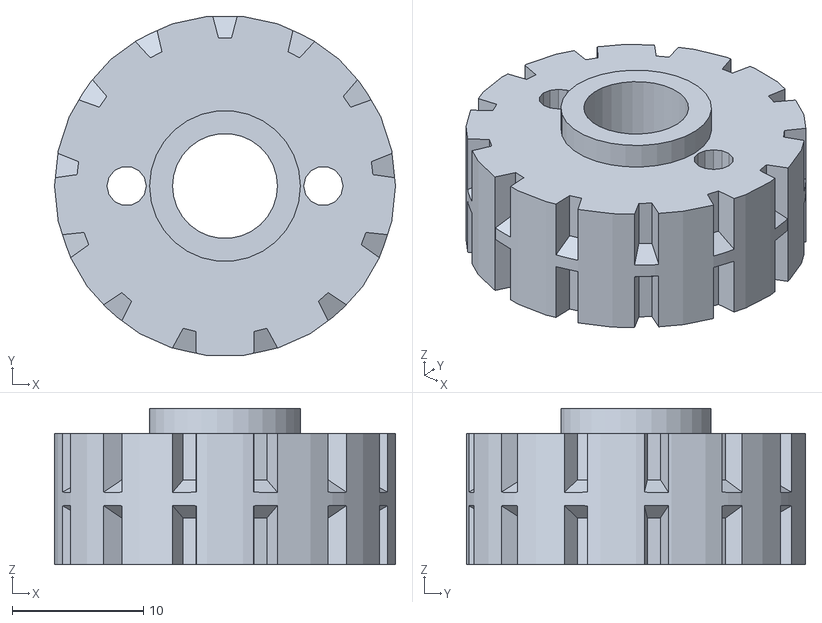
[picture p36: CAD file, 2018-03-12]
documentation/Lidar-Mount-3D-Print/Slipring.stl
26.0 x 25.9 x 11.9

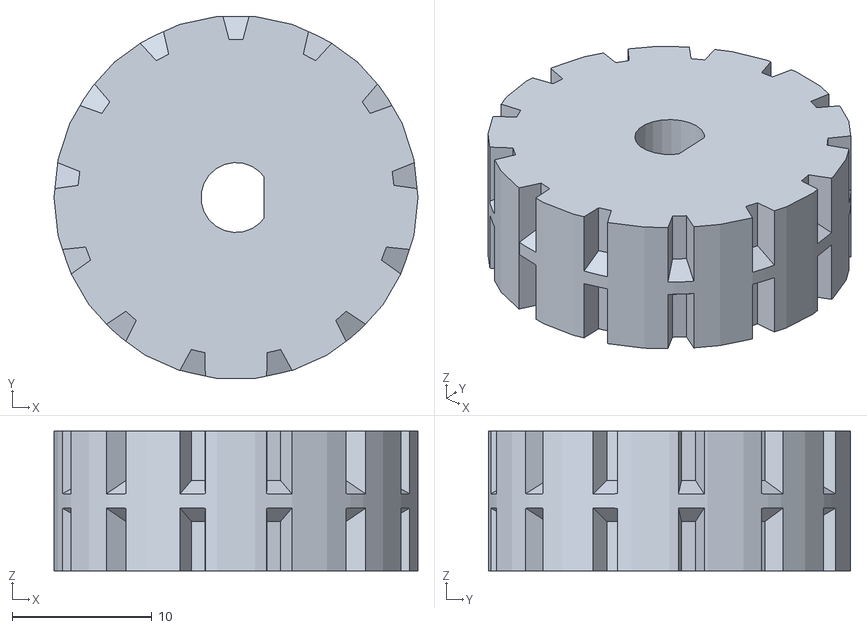
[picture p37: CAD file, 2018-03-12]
documentation/Lidar-Mount-3D-Print/Motor.stl
26.0 x 25.9 x 10.0

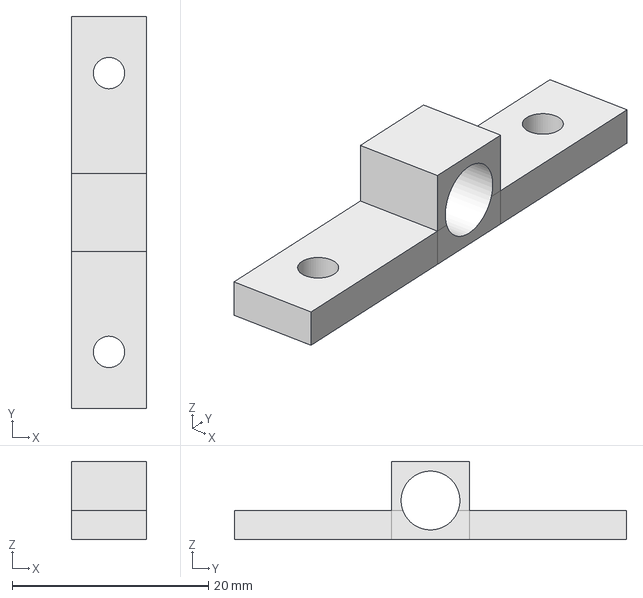
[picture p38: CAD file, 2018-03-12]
documentation/Lidar-Mount-3D-Print/LIDAR-Mount.fcstd
7.62 x 40.0 x 8.00 mm

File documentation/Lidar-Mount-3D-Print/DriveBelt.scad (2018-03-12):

$fs = 0.7;

wheelSize = 13;

playLooseFit = 0.2;

trackWidth = 10;
trackThickness = 0.7;
trackTeethSpacing = (wheelSize * 6.2831) / 13;

trackTeethHeight = 1.5;	
trackTeethBaseWidth = 1.5;	
trackTeethTopWidth = 0.6;

trackTeethNoslipBase = 1; 
trackTeethNoslipTop = 3;

module track_basicring(r = 10) render(convexity = 3) {
	difference() {
		cylinder(r = r + trackThickness, h = trackWidth);
		translate([0, 0, -0.1]) cylinder(r = r, h = trackWidth + 0.2);
	}
}

module track_tooth() {
	teethOffset = $teeth_use_offset ? playLooseFit : 0;

	trackTeethBaseWidth = trackTeethBaseWidth + teethOffset * 2;
	trackTeethTopWidth = trackTeethTopWidth + teethOffset * 2;
	trackTeethHeight = trackTeethHeight + teethOffset;

	linear_extrude(height = trackWidth) {
		polygon([	[trackTeethBaseWidth/2, 0],
						[trackTeethTopWidth/2, -trackTeethHeight],
						[-trackTeethTopWidth/2, -trackTeethHeight],
						[-trackTeethBaseWidth/2, 0]]);
	}
}

module track_teeth_noslip(r = 10) {
	teethOffset = $teeth_use_offset ? playLooseFit : 0;

	trackTeethHeight = trackTeethHeight + teethOffset;

	rotate_extrude() {
		polygon([	[r - trackTeethHeight - 0.01, trackTeethNoslipTop/2],
						[r - trackTeethHeight - 0.01, -trackTeethNoslipTop/2],
						[r + 0.01, -trackTeethNoslipBase/2],
						[r + 0.01, trackTeethNoslipBase/2]]);
	}
}

module track_teeth(r = 10, tRadius = -1) {
	tRadius = (tRadius < 0) ? r : tRadius;
	
	trackCircumference = 6.28318 * tRadius;
	teethNum = floor(trackCircumference / trackTeethSpacing);

	intersection() {
		for(i=[0:360/teethNum:360]) rotate([0, 0, i]) render() difference() {
			translate([0, r, 0]) track_tooth();
			translate([0, 0, trackWidth/2]) track_teeth_noslip(r);
		}

		cylinder(r = r + 0.001, h = trackWidth);
	}
}

module track(r = 10, rShrink = 0, clearance_offset = false) {
	$teeth_use_offset = clearance_offset;

	track_teeth(r - rShrink, r);
	track_basicring(r - rShrink);
}

module basic_wheel() render(convexity = 3) {
	difference() {
		cylinder(r = wheelSize, h = trackWidth);
		track(r = wheelSize, clearance_offset = true);
	}
}

module motor_axis() {
	difference() {
		cylinder(d = 5, h = 100);
		translate([2, -5, 0]) cube([5, 10, 100]);
	}
}
	
module motor_wheel() {
	difference() {
		basic_wheel(); 
		translate([0,0, -0.1]) motor_axis();
	}
}

module slipring_wheel() {
	difference() {
		union() {
			basic_wheel();
			translate([0, 0, trackWidth - 0.1]) cylinder(d = 11.5, h = 2);
		}
		translate([0, 0, -0.1]) cylinder(d = 8, h = 100);
		
		for(x = [-1, 1]) translate([x*7.5, 0, -0.1]) cylinder(d = 3, h = 100);
	}
}

track(r = wheelSize + (80)/6.28);
		

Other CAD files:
robot/OldVersions/base.0002.ipt
robot/OldVersions/dessus.0002.ipt
robot/OldVersions/tube.0001.ipt
robot/Pièce_roue folle.ipt
robot/Robot.iam
robot/Servomoteur HS-311.CATPart
robot/Servomoteur HS-311.ipt
robot/base.ipt
robot/dessus.ipt
robot/tube.ipt

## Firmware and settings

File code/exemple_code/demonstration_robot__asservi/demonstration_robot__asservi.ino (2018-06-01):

#include <SimpleTimer.h>

// parti lidar
#include <Servo.h>
//branchements  :
/*servomoteur bleu horizontale : 12
 * servomoteur bleu verticale : 13 
 * + fils + des servomoteurs branchés à la tension des piles (4*1.5v) 
 * lidar :  fil blanc =>rx1 18 
 *          fil vert =>tx1 19
 *          fil violet et noir du => non branchés
 * capa aux bornes de l'alime des piles (4*1.5 v)
 *          
*/
unsigned int distance;
int angle = 20;
boolean montee = true;

boolean change=false;

Servo servoX;
Servo servoY;

SimpleTimer timer;    // Timer pour échantillonnage



// parti robot 

//###########################
//##asservissement vitesse###
 unsigned int tick_codeuse_vit_A = 0;  // Compteur de tick de la codeuse
unsigned int tick_codeuse_vit_B = 0; 
 int vitMoteur_A = 0;   // Commande du moteur
 int vitMoteur_B = 0;
const int frequence_echantillonnage = 100;  // Fréquence d'exécution de l'asservissement
const int rapport_reducteur = 80;          // Rapport entre le nombre de tours de l'arbre moteur et de la roue
const int tick_par_tour_codeuse = 4;  //64 tick sur deux capteurs hall, ici on a pris un seul capteur


//consigne en tour/s
float consigne_moteur_A = 0.5; //  Consigne nombre de tours de roue par seconde
float consigne_moteur_B = 0.5;

// init calculs asservissement PID
 float erreur_precedente_A = consigne_moteur_A; // (en tour/s)
 float erreur_precedente_B = consigne_moteur_B;
float somme_erreur_A = 0;
float somme_erreur_B = 0;

//Definition des constantes du correcteur PID
float kp =120;// 150          // Coefficient proportionnel    choisis par tatonnement sur le moniteur. Ce sont les valeurs qui donnaient les meilleures performances
float ki = 40;// 25      // Coefficient intégrateur
float kd = 45;// 45           // Coefficient dérivateur

int etape = 1;

boolean fin_A=false;
boolean fin_B=false;
boolean ok=true;

//###########################

// Motor 1
int dir1PinA = 4;
int dir2PinA = 5;
int speedPinA = 9; // Needs to be a PWM pin to be able to control motor speed

// Motor 2
int dir1PinB = 6;
int dir2PinB = 7;
int speedPinB = 10; // Needs to be a PWM pin to be able to control motor speed

//Déclaration des variables permettant la commandes des moteurs A et B
int inByte_A = 0; 
int inByte_B = 0;

// variables de comptage des roues codeuses
 unsigned int tick_codeuse_A = 0; 
 unsigned int tick_codeuse_B = 0; 

int avancer_cm=0; // variable du nombre de centimètre à avancer
int avancer_tick=0; // variable du nombre de "tick" à effectuer

int speed_B;
 int speed_A;

float entraxe_roue=19.1; //entraxe de nos roues :18.9cm
float perim=entraxe_roue*3.14159; //perimetre du cercle parcourue par les roues lors d'un tour du robot dur lui même
float diametre_roue= 6.5 ;//diametre de nos roue : 6.5cm


void setup() {  // Setup runs once per reset
    
    // setup lidar
    
    Serial1.begin(115200);
    //Serial.begin(115200);
    Serial2.begin(115200);
    
    servoX.attach(12);
    servoY.attach(13);
    
    servoX.write(30);
    servoY.write(97);
    delay(1000);


  // setup robot
  
  //Define L298N Dual H-Bridge Motor Controller Pins
  
  pinMode(dir1PinA,OUTPUT);
  pinMode(dir2PinA,OUTPUT);
  pinMode(speedPinA,OUTPUT);
  pinMode(dir1PinB,OUTPUT);
  pinMode(dir2PinB,OUTPUT);
  pinMode(speedPinB,OUTPUT);
  
  attachInterrupt(digitalPinToInterrupt(2), compteur_A, CHANGE); // Interruption sur tick de la codeuse (interruption 0 = pin2 arduino mega)
  attachInterrupt(digitalPinToInterrupt(3), compteur_B, CHANGE);
  
  
  //Serial.println(perim);
  
  timer.setInterval(1000/frequence_echantillonnage,asservissement_A); 
}


void loop() {
    timer.run();
    
    if (etape==1 and ok){
      prise();
      delay(2000);
      reinitialise();
      avancer_tick=action(1,27);
      
    }else if (etape==2 and ok){
      prise();
      delay(2000);
      reinitialise();
      avancer_tick=action(4,90);
    
    }else if (etape==3 and ok){
      prise();
      delay(2000);
      reinitialise();
      avancer_tick=action(1,3);
    }
}

// fonction lidar :
void prise(){
  while (true){
    
    distance = mesure();
    delay(10); //  quoi sert ce delay ???
    String res = String(distance)+";"+String(angle)+";";
    //Serial.println(res);
    Serial2.println(res);
    
    servoX.write(angle);
    if (change){
      change = false;
      break;
    }
    delay(40);
//    if(montee){
//       if(angle<=160){
//        angle ++;
//       }else{
//          montee = false;
//       }
//    }else{
//      if(angle>=20){
//        angle --;
//       }else{
//          montee = true;      
//          break;
//       }
    if (angle<160) {
      angle ++;
    }else {
      angle = 19;
      change =true;
    }
  }
}

unsigned int mesure(){
    unsigned int t2;
    while( Serial1.available()>=9){  
      if((0x59 == Serial1.read()) && (0x59 == Serial1.read())){ //Byte1 & Byte2
          unsigned int t1 = Serial1.read(); //Byte3
          t2 = Serial1.read(); //Byte4
          
          t2 <<= 8;
          t2 += t1;
          //Serial.print(t2);
  
          Serial1.read(); //Byte5
          Serial1.read(); //Byte6
          
          for(int i=0; i<3; i++) { 
              Serial1.read(); ////Byte7,8,9
          }
      }
    }
  return t2;

}


// fonction robot

void reinitialise(){
   tick_codeuse_vit_A = 0;  // Compteur de tick de la codeuse
   tick_codeuse_vit_B = 0; 
   vitMoteur_A = 0;   // Commande du moteur
   vitMoteur_B = 0;
  consigne_moteur_A = 0; //  Consigne nombre de tours de roue par seconde
  consigne_moteur_B = 0;


 erreur_precedente_A = consigne_moteur_A; // (en tour/s)
 erreur_precedente_B = consigne_moteur_B;
  somme_erreur_A = 0;
  somme_erreur_B = 0;
  ok=false;
      fin_B=false;
      fin_A=false;
 timer.restartTimer(0);

  }

void deplacement(){
   

  /*    Serial.print(tick_codeuse_A);
      Serial.print(" | ");
      Serial.println(tick_codeuse_B);
   */// debogages 
      
     
    if(tick_codeuse_A<avancer_tick){
      
      
      switch (inByte_A) {
      
      //______________Motor 1______________
      
      case '1': 
      
      analogWrite(speedPinA, speed_A);//Sets speed variable via PWM 
      digitalWrite(dir1PinA, LOW);
      digitalWrite(dir2PinA, HIGH);
    
      
      break;
      
      case '2': // Motor 1 Stop (Freespin)
      analogWrite(speedPinA, 0);
      digitalWrite(dir1PinA, LOW);
      digitalWrite(dir2PinA, HIGH);
      
      break;
      
      case '3': // Motor 1 Reverse
      analogWrite(speedPinA, speed_A);
      digitalWrite(dir1PinA, HIGH);
      digitalWrite(dir2PinA, LOW);
      
      break;
      
      default:
      // turn all the connections off if an unmapped key is pressed:
      for (int thisPin = 2; thisPin < 11; thisPin++) {
      digitalWrite(thisPin, LOW);
      
      }
        }
          }
    else {
      analogWrite(speedPinA, 0);
      digitalWrite(dir1PinA, LOW);
      digitalWrite(dir2PinA, HIGH);
      
     }
    
     if(tick_codeuse_B<avancer_tick){
      
      switch (inByte_B) {
      
      //______________Motor 1______________
      
      case '4': // Fait avancer les deux moteurs dans les sens de la marche
     
      analogWrite(speedPinB, speed_B);
      digitalWrite(dir1PinB, LOW);
      digitalWrite(dir2PinB, HIGH);
      
      
      break;
      
      case '6': // Motor 2 Reverse
      analogWrite(speedPinB, speed_B);
      digitalWrite(dir1PinB, HIGH);
      digitalWrite(dir2PinB, LOW);
     
      break;
      
     
      default:
      // turn all the connections off if an unmapped key is pressed:
      for (int thisPin = 2; thisPin < 11; thisPin++) {
      digitalWrite(thisPin, LOW);
      }
        }
          }
    else {
      
      analogWrite(speedPinB, 0);
      digitalWrite(dir1PinB, LOW);
      digitalWrite(dir2PinB, HIGH);
     }
  
}      

///* Interruption sur tick de la codeuse */
void compteur_A(){
    tick_codeuse_A=tick_codeuse_A+1;  // On incrémente le nombre de tick de la codeuse
    tick_codeuse_vit_A=tick_codeuse_vit_A+1;
    //Serial.println(tick_codeuse);
}
void compteur_B(){
    tick_codeuse_B=tick_codeuse_B+1;// On incrémente le nombre de tick de la codeuse
    tick_codeuse_vit_B=tick_codeuse_vit_B+1;
    //Serial.println(tick_codeuse);
}

int convert(float cm){
  float roue=cm/(diametre_roue*3.14); 
  int tick=roue*80*4;
  return tick;
  }

float action(int commande, int dist){ 
  /* variable commande : 
      1 : avancer
      2 : reculer
      3 : tour sens horaire
      4 : tour sens anti-horaire
  */
  
  // variable dist => distance en cm
  // note : si la commande est un tour , la variable dist est l'angle en degré

  //renvoi le nombre de tick permettant de faire le déplacement

  switch (commande) {
    
    case 1 :
      //paramétrage du sens de rotation des moteurs
      inByte_A = '1'; 
      inByte_B = '4';

      //initialisation des compteurs
      tick_codeuse_A = 0; 
      tick_codeuse_B = 0; 
      
      consigne_moteur_B = 0.5;
      consigne_moteur_A = 0.5; 

      //avancer_tick=convert(dist);
     
      return convert(dist);
    break;
    
    case 2 :
      //paramétrage du sens de rotation des moteurs
      inByte_A = '3'; 
      inByte_B = '6';

      //initialisation des compteurs
      tick_codeuse_A = 0; 
      tick_codeuse_B = 0; 

      consigne_moteur_B = 0.5;
      consigne_moteur_A = 0.5;

      //avancer_tick=convert(dist);
      
      return convert(dist);
    break;
    
    // fonctionne mieux en 4(sensanti-horaire
//    case 3 :
//       // on effectue dans ce cas un tour, la variable dist est donc langle en degrés
//      //paramétrage du sens de rotation des moteurs
//      inByte_A = '3'; 
//      inByte_B = '4';
//
//      //initialisation des compteurs
//      tick_codeuse_A = 0; 
//      tick_codeuse_B = 0; 
//
//      consigne_moteur_B = 0.5;
//      consigne_moteur_A = 0.5;

      
      
      return convert((dist*perim)/360);
    break;
    case 4 :
      // on effectue dans ce cas un tour, la variable dist est donc langle en degrés
      //paramétrage du sens de rotation des moteurs
      inByte_A = '1'; 
      inByte_B = '6';

      //initialisation des compteurs
      tick_codeuse_A = 0; 
      tick_codeuse_B = 0; 

      consigne_moteur_B = 0.5;
      consigne_moteur_A = 0.5;

      
      return convert((dist*perim)/360);
    break;
    default :
    return 0;

//    case '4'  : 
  }
    

}

/* Interruption pour calcul du P */
void asservissement_A(){
  if(avancer_tick>tick_codeuse_A ){
    if(avancer_tick-tick_codeuse_A<250){
          consigne_moteur_A=0.5;
          
        }
        
    // Calcul de l'erreur
    int frequence_codeuse_A = frequence_echantillonnage*tick_codeuse_vit_A; //100*tick_codeuse
     float vit_roue_tour_sec_A = (float)frequence_codeuse_A/(float)tick_par_tour_codeuse/(float)rapport_reducteur;    //(100*tick_codeuse)/32/19 
    float erreur_A = consigne_moteur_A - vit_roue_tour_sec_A; // pour le proportionnel
    somme_erreur_A += erreur_A; // pour l'intégrateur
     float delta_erreur_A = erreur_A-erreur_precedente_A;  // pour le dérivateur
    erreur_precedente_A = erreur_A;
    
    // Réinitialisation du nombre de tick de la codeuse
    tick_codeuse_vit_A=0;
  
    // P : calcul de la commande
    speed_A = kp*erreur_A + ki*somme_erreur_A + kd*delta_erreur_A;  //somme des tois erreurs
    
    // Normalisation et contrôle du moteur
    if (speed_A > 255) {
      speed_A = 255;  // sachant que l'on est branché sur un pont en H L293D
    } 
    else if (speed_A <0) {
      speed_A = 0;
    }
  }else {
    fin_A=true;
    }
  if(avancer_tick>tick_codeuse_B ){
    if(avancer_tick-tick_codeuse_B<250){
          consigne_moteur_B=0.5;
          
        }
        
    // Calcul de l'erreur
    int frequence_codeuse_B = frequence_echantillonnage*tick_codeuse_vit_B; //100*tick_codeuse
     float vit_roue_tour_sec_B = (float)frequence_codeuse_B/(float)tick_par_tour_codeuse/(float)rapport_reducteur;    //(100*tick_codeuse)/32/19 
    float erreur_B = consigne_moteur_B - vit_roue_tour_sec_B; // pour le proportionnel
    somme_erreur_B += erreur_B; // pour l'intégrateur
     float delta_erreur_B = erreur_B-erreur_precedente_B;  // pour le dérivateur
    erreur_precedente_B = erreur_B;
    
    // Réinitialisation du nombre de tick de la codeuse
    tick_codeuse_vit_B=0;
  
    // P : calcul de la commande
    speed_B = kp*erreur_B + ki*somme_erreur_B + kd*delta_erreur_B;  //somme des tois erreurs
    
    // Normalisation et contrôle du moteur
    if (speed_B > 255) {
      speed_B = 255;  // sachant que l'on est branché sur un pont en H L293D
    } 
    else if (speed_B <0) {
      speed_B = 0;
    }
  }else {
    fin_B=true;
  }
  if(fin_A and fin_B){
     etape=etape+1;
     ok=true;
  }
  //Serial.println(speed_B);
  deplacement();
}

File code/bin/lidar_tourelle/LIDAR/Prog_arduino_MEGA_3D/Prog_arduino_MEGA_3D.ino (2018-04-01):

//Largement inspiré de : www.qcontinuum.org/lidar

#include <Servo.h>
#include <LIDARLite.h>
#include <LiquidCrystal.h>

Servo servoX;
Servo servoY;
LIDARLite lidar;
LiquidCrystal lcd(8, 9, 4, 5, 6, 7);

// Minimum and maximum servo angle in degrees
// Modify to avoid hitting limits imposed by pan/tilt bracket geometry
int minPosX = 0;
int maxPosX = 180;
int minPosY = 60;
int maxPosY = 130;

int buttonPin = A0;
int buttonValue = 0;
int buttonThreshold = 50;
int lastPosX = 0;
int lastPosY = 0;
int loopCount = 0;
int radius = 0;
int lastRadius = 0;
boolean selectButtonPressed = false;
boolean scanning = false;
boolean scanDirection = false;
int scanIncrement = 1;
int posX = (maxPosX + minPosX) / 2;
int posY = (maxPosY + minPosY) / 4;
float pi = 3.14159265;
float deg2rad = pi / 180.0;

int strength;// LiDAR signal strength
int check;// check numerical value storage
int i;
int j=0;
int uart[9];// store data measured by LiDAR
const int HEADER=0x59;// data package frame header

void setup() {
  lcd.begin(16, 2);
  updateModeDisplay();
  lidar.begin(0, true);
  lidar.configure(0);
  servoX.attach(2);
  servoY.attach(3);
  servoX.write(posX);
  servoY.write(posY);
  Serial.begin(9600);
  Serial1.begin(115200);//set the Baud rate of LiDAR and Arduino serial port
}

void loop() {
//  Serial.println("START----------START----------START----------START"); //------------------------------------------------------------------
    buttonValue = 740;

//  buttonValue = analogRead(buttonPin);
//*************************************************************************
  if (scanning) { 
    if (abs(buttonValue - 741) < buttonThreshold) {
        if (!selectButtonPressed) {
        // switch to manual scan mode
        selectButtonPressed = true;
        scanning = false;
        updateModeDisplay();
      }
    } else {
      selectButtonPressed = false;
    }
    if (scanDirection) {
      posX += scanIncrement;
    } else {
      posX -= scanIncrement;
    }
    if (posX > maxPosX || posX < minPosX) {
      // hit limit X limit, reverse auto scan direction
      scanDirection = !scanDirection;
      posY += scanIncrement;
      if (posY > maxPosY) {
        // completed auto scan, return to manual scan mode
        scanning = false;
        updateModeDisplay();
      }
    }
  }
   else {
    if (abs(buttonValue - 741) < buttonThreshold) {
        if (!selectButtonPressed) {
        // switch to auto scan mode
        selectButtonPressed = true;
        scanning = true;
        posX = minPosX;
        posY = minPosY;
        scanDirection = true;
        updateModeDisplay();
      }
    } else if (abs(buttonValue - 505) < buttonThreshold) {
      // manual scan left
      posX += 1;
     } else if (abs(buttonValue - 329) < buttonThreshold) {
      // manual scan down
      posY -= 1;
    } else if (abs(buttonValue - 145) < buttonThreshold) {
      // manual scan up
      posY += 1;
    } else if (abs(buttonValue - 0) < buttonThreshold) {
      // manual scan right
      posX -= 1;
     } else {
      selectButtonPressed = false;
     }
  }
//*************************************************************************
  posX = min(max(posX, minPosX), maxPosX);
  posY = min(max(posY, minPosY), maxPosY);
  bool moved = moveServos();
  displayPosition();

  loopCount += 1;
//  Serial.println(loopCount); //------------------------------------------------------------------
  
//*****************RECALIBRAGE OU PAS***************************  
while(j==0) {
  if (Serial1.available()) {
      if(Serial1.read()==HEADER) {
         uart[0]=HEADER;
         delay(1);
         if(Serial1.read()==HEADER) {
             uart[1]=HEADER;
             for(i=2;i<9;i++) {
                 uart[i]=Serial1.read(); }
             check=uart[0]+uart[1]+uart[2]+uart[3]+uart[4]+uart[5]+uart[6]+uart[7];
             if(uart[8]==(check&0xff)) {
                 radius=uart[2]+uart[3]*256;// calculate distance value
                 strength=uart[4]+uart[5]*256;// calculate signal strength value               
                 j=1;
}}}}
   if (Serial1.available()) {    
       j=0;       
   }
   } 
//Serial.println(radius);
 j=0;
//***************************************************************  

  if (abs(radius - lastRadius) > 2)
  {
    lastRadius = radius;
    lcd.setCursor(8, 0);
    lcd.print("D:" + String(radius / 100.0, 2) + "  ");
  }

//    Serial.print("scanning = ");//------------------------------------------------------------------  
//    Serial.print(scanning);//------------------------------------------------------------------  
//    Serial.print("  moved = ");//------------------------------------------------------------------  
//    Serial.println(moved);//------------------------------------------------------------------  

    
  if (scanning || moved) {
 //   Serial.println("scanning");//------------------------------------------------------------------   
    float azimuth = posX * deg2rad;
    float elevation = (180 - maxPosY + posY) * deg2rad;
    double x = radius * sin(elevation) * cos(azimuth);
    double y = radius * sin(elevation) * sin(azimuth);
    double z = radius * cos(elevation);
    Serial.println(String(-x, 5) + " " + String(y, 5) + " " + String(-z, 5));
  }
}

bool moveServos()
{

  bool moved = false;
  static int lastPosX;
  static int lastPosY;
  int delta = 0;  
  if (posX != lastPosX) {
    delta += abs(posX - lastPosX);
    servoX.write(180-posX);
    lastPosX = posX;
    moved = true;
 //     Serial.println("SERVO1");//------------------------------------------------------------------
  }
  if (posY != lastPosY) {
    delta += abs(posY - lastPosY);
    servoY.write(180-posY);
    lastPosY = posY;
    moved = true;
//      Serial.println("SERVO2");//------------------------------------------------------------------
  }
//    Serial.print("moved = ");//------------------------------------------------------------------
 //   Serial.println(moved);//------------------------------------------------------------------
  delay(30);
  return moved;

}

void displayPosition()
{
  static int lastPosX;
  static int lastPosY;
  if (posX != lastPosX) {
    lcd.setCursor(0, 0);
    lcd.print("X:" + String(posX) + "  ");
    lastPosX = posX;
  }
  if (posY != lastPosY) {
    lcd.setCursor(0, 1);
    lcd.print("Y:" + String(posY) + "  ");
    lastPosY = posY;
  }  
//    Serial.println("displayPosition");//------------------------------------------------------------------
}

void updateModeDisplay()
{
  lcd.setCursor(8, 1);
  if (scanning) {
    lcd.print("Scanning");
  } else {
    lcd.print("Manual  ");
  }
}

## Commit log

2017-12-21 Create Arduino 1
2017-12-21 Create Arduino 2
2017-12-21 Create liste de materiel.md
2017-12-21 Update liste de materiel.md
2017-12-22 Rename liste de materiel.md to liste du materiel.md
2018-01-10 changements de dossier, nom etc
    Verifier si tout marche bien
2018-01-22 changement de nom
2018-01-27 supression arduino files
2018-04-01 Réagencement des fichiers
2018-05-03 combo lidar+ robot !!!!
2018-05-05 changement de mfzef
2018-05-14 Create Pin serial prot esp 32
2018-05-25 communication esp32 finie
